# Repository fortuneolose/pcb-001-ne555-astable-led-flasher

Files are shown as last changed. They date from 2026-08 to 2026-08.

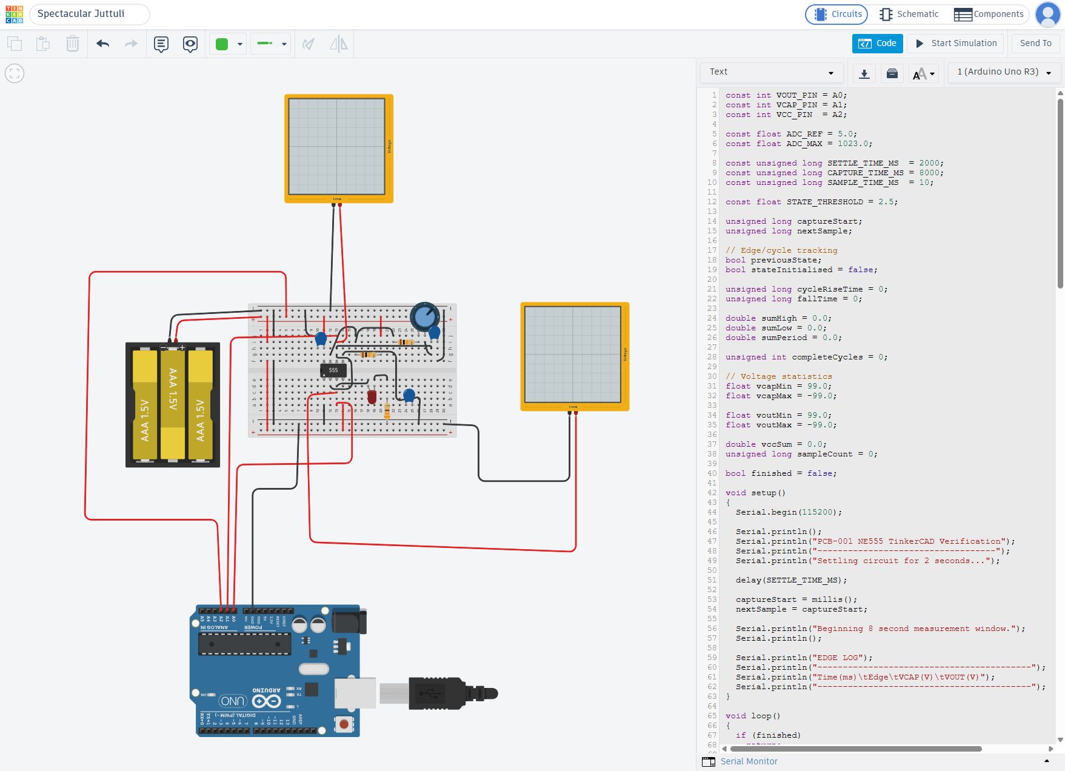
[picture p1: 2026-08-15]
simulation/tinkercad/evidence/arduino-code-panel.png

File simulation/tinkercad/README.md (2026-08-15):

# PCB-001 — Adjustable NE555 Astable LED Flasher

## Purpose

This directory preserves reproducible artifacts and evidence from the Tinkercad virtual breadboard verification stage.

The interactive Tinkercad circuit is cloud-hosted. This directory preserves code, measurements, circuit documentation, screenshots, and verification evidence derived from the live model. LTspice remains the precision electrical simulation model. Tinkercad represents the virtual breadboard and implementation translation. KiCad will become the authoritative PCB schematic and layout source.

The Tinkercad stage verifies practical pin mapping, component polarity, breadboard connectivity, potentiometer operation, instrumentation, and observable circuit behaviour. Static screenshots and the Arduino logger source were extracted directly from the live model during the 2026-08-14 inspection workflow.

## Current Verification Gates

- G1A Analytical Design: PASS
- G1B LTspice Full-Range Verification: PASS
- G1C LED Output Verification: PASS
- G1D Tinkercad Virtual Breadboard Verification: PASS

G1D is supported by minimum, midpoint, and maximum operating-point measurements.

## Live Project Metadata

- Project name: Spectacular Juttuli
- Tinkercad project URL: https://www.tinkercad.com/things/cFG6PsBppi5-spectacular-juttuli/editel
- Live inspection workflow date: 2026-08-14

## Preserved Static Evidence

- `evidence/breadboard-overview.png`
- `evidence/ne555-pin-wiring.png`
- `evidence/timing-network.png`
- `evidence/potentiometer-wiring.png`
- `evidence/led-output-stage.png`
- `evidence/arduino-logger-wiring.png`
- `evidence/arduino-code-panel.png`
- `evidence/tinkercad-schematic-view.png`

These files are genuine screenshots from the stopped live Tinkercad project. They do not establish powered waveforms or new measurement results.

## Corrected Dynamic Verification

On 2026-08-15, the Arduino logger was hardened against partial boundary cycles; the corrected source is preserved in commit `67e7f33`. The minimum, midpoint, and maximum operating points were re-run and all three passed. Genuine Serial Monitor and potentiometer evidence was captured at every operating point, with useful VOUT and VCAP scope evidence captured at midpoint and maximum. The electrical circuit itself was unchanged.

Corrected result records:

- `results/minimum_corrected_logger_2026-08-15.txt`
- `results/midpoint_corrected_logger_2026-08-15.txt`
- `results/maximum_corrected_logger_2026-08-15.txt`

Dynamic evidence:

- `evidence/potentiometer-minimum-2026-08-15.png`
- `evidence/serial-minimum-corrected-2026-08-15.png`
- `evidence/potentiometer-midpoint-2026-08-15.png`
- `evidence/serial-midpoint-corrected-2026-08-15.png`
- `evidence/scope-vout-midpoint-2026-08-15.png`
- `evidence/scope-vcap-midpoint-2026-08-15.png`
- `evidence/potentiometer-maximum-2026-08-15.png`
- `evidence/serial-maximum-corrected-2026-08-15.png`
- `evidence/scope-vout-maximum-2026-08-15.png`
- `evidence/scope-vcap-maximum-2026-08-15.png`

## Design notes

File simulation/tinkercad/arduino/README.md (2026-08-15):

# Arduino Instrumentation

The Arduino Uno R3 is instrumentation only; it does not implement the oscillator. The NE555 and its external timing network generate the oscillation.

## Intended Measurement Channels

- A0 -> NE555 VOUT / pin 3
- A1 -> VCAP timing-capacitor node
- A2 -> Tinkercad battery positive rail / VCC measurement
- GND -> circuit common ground

## Authoritative Source

The authoritative logger source was extracted verbatim from the live Tinkercad model during the 2026-08-14 inspection workflow. It is stored at:

`simulation/tinkercad/arduino/pcb001_ne555_logger.ino`

Do not reconstruct or replace this source from memory. Future changes must remain traceable to an explicitly reviewed live-model revision.

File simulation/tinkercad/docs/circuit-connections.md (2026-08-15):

# Circuit Connections

This document records design intent and the completed 2026-08-14 live-model inspection of the virtual breadboard.

## NE555 Connections

| Physical implementation item | Design intent | Live Tinkercad inspection status |
| --- | --- | --- |
| Pin 1 GND | GND | VERIFIED |
| Pin 2 TRIG | VCAP | VERIFIED |
| Pin 3 OUT | red LED -> 330 ohm -> GND | VERIFIED |
| Pin 4 RESET | positive supply | VERIFIED |
| Pin 5 CTRL | 10 nF capacitor -> GND | VERIFIED |
| Pin 6 THRS | VCAP | VERIFIED |
| Pin 7 DIS | RA/RB junction | VERIFIED |
| Pin 8 VCC | positive supply | VERIFIED |

## Timing Network and Supporting Components

Intended timing path:

```text
positive supply
-> RA = 10 kOhm
-> pin 7 DIS
-> fixed RB = 10 kOhm
-> 100 kOhm potentiometer used as rheostat
-> VCAP
-> C1 = 10 uF
-> GND
```

| Physical implementation item | Design intent | Live Tinkercad inspection status |
| --- | --- | --- |
| RA | 10 kOhm from positive supply to pin 7 DIS | VERIFIED |
| Fixed RB | 10 kOhm from pin 7 DIS toward the potentiometer | VERIFIED |
| Potentiometer | 100 kOhm, used as a rheostat between fixed RB and VCAP | VERIFIED |
| C1 timing capacitor | 10 uF from VCAP to GND | VERIFIED |
| CTRL capacitor | 10 nF from pin 5 CTRL to GND | VERIFIED |
| Decoupling capacitor | 100 nF VCC-to-GND supply decoupling | VERIFIED |
| LED output stage | red LED with 330 ohm resistor to GND | VERIFIED |
| Supply | 3 x AAA representation; nominal 4.5 V and approximately 4.49 V in recorded measurements | VERIFIED |
| Overall timing-network implementation | RA, fixed RB, rheostat, VCAP, and timing capacitor topology | VERIFIED |

## Potentiometer Wiring

- Value = 100 kOhm
- Terminal 1 -> fixed 10 kOhm RB
- Wiper -> VCAP
- Terminal 2 -> VCAP
- Wiper tied to outer terminal 2
- Used as a rheostat

## Reference-Designator Traceability

Design nomenclature:

- C1 = 10 uF timing capacitor
- C2 = 10 nF CTRL capacitor
- C3 = 100 nF decoupling capacitor

Live Tinkercad reference labels:

- CC1 = 10 uF timing capacitor
- C1 = 10 nF CTRL capacitor
- CC3 = 100 nF decoupling capacitor

This is a reference-designator naming difference only, not an electrical discrepancy. The exact powered rail voltage was not re-measured during this static inspection because the simulation remained stopped.

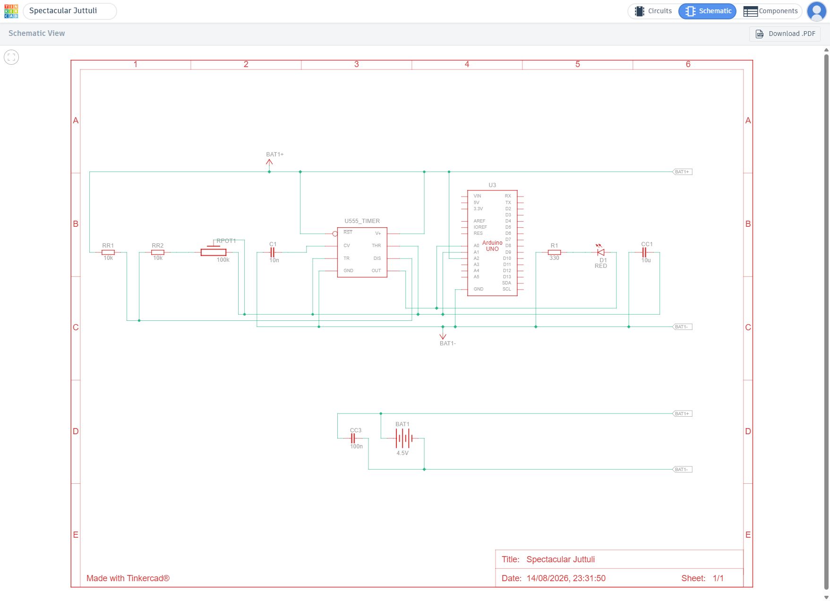
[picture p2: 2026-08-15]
simulation/tinkercad/evidence/tinkercad-schematic-view.png

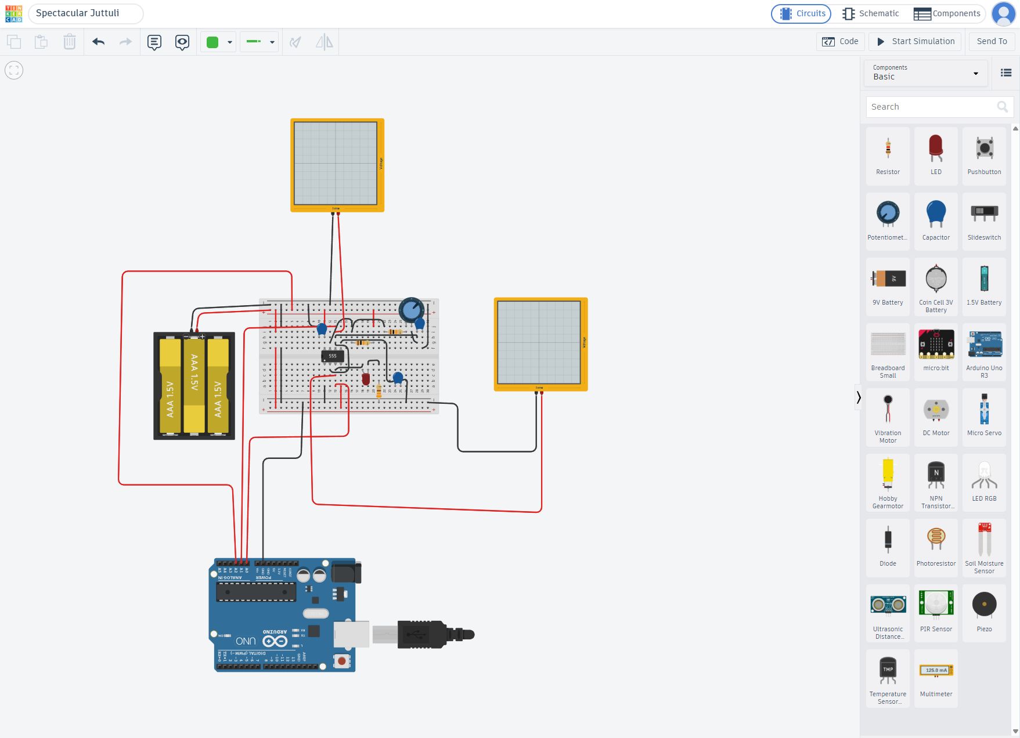
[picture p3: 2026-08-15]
simulation/tinkercad/evidence/breadboard-overview.png

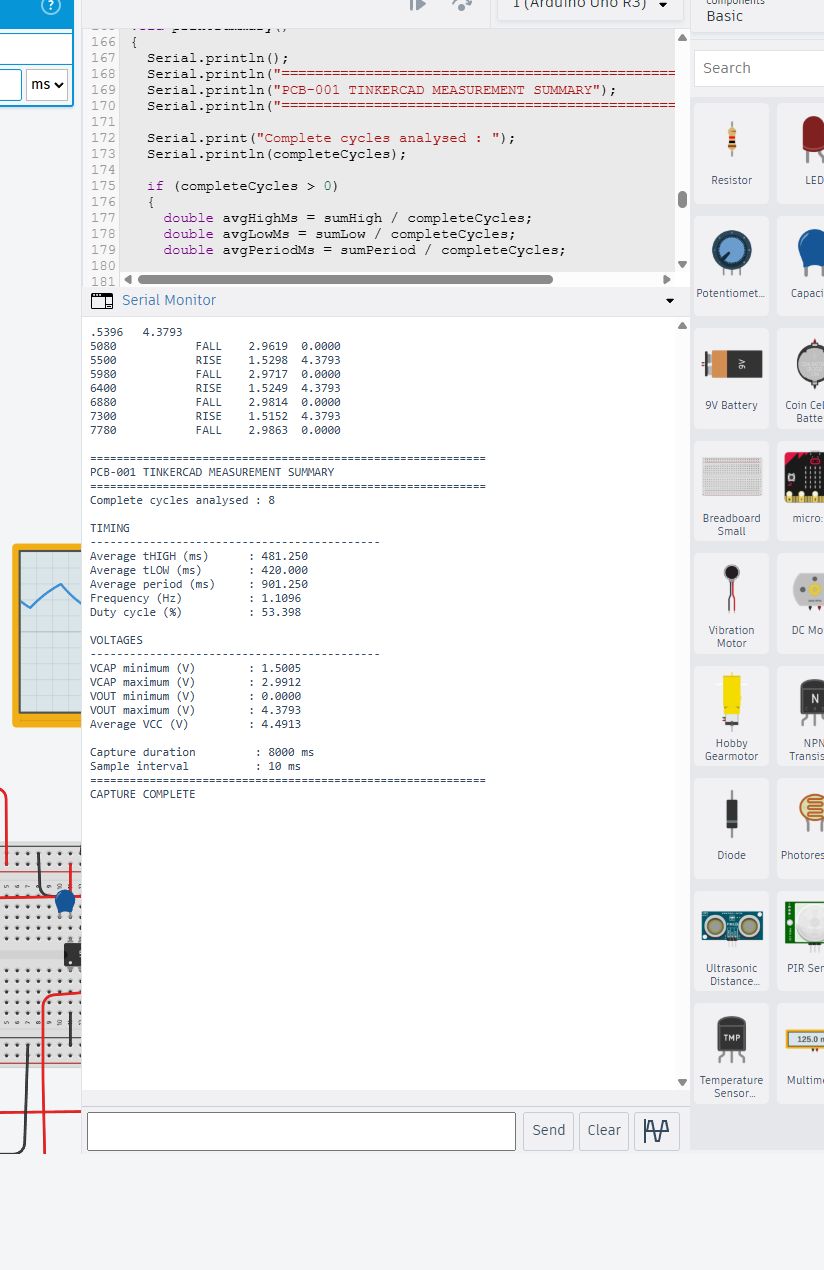
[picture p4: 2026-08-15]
simulation/tinkercad/evidence/serial-midpoint-corrected-2026-08-15.png

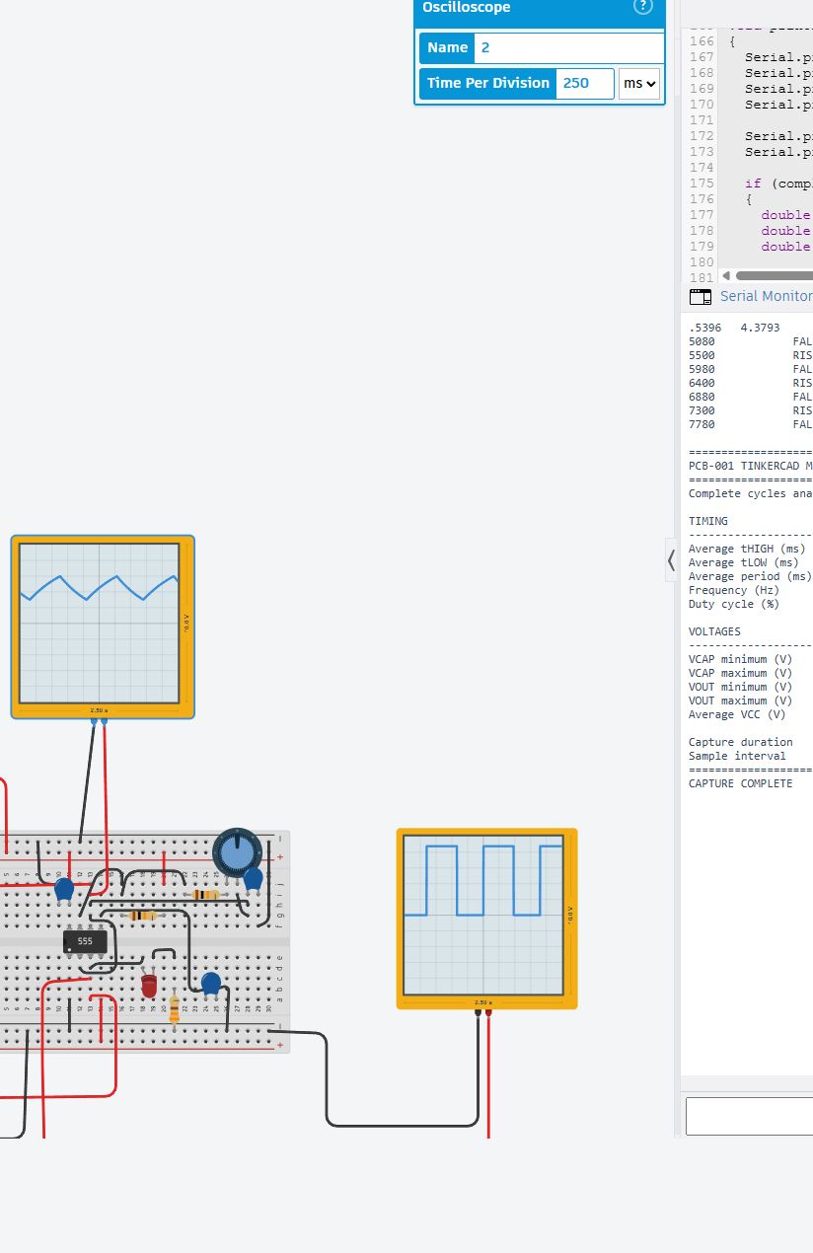
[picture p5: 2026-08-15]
simulation/tinkercad/evidence/scope-vcap-midpoint-2026-08-15.png

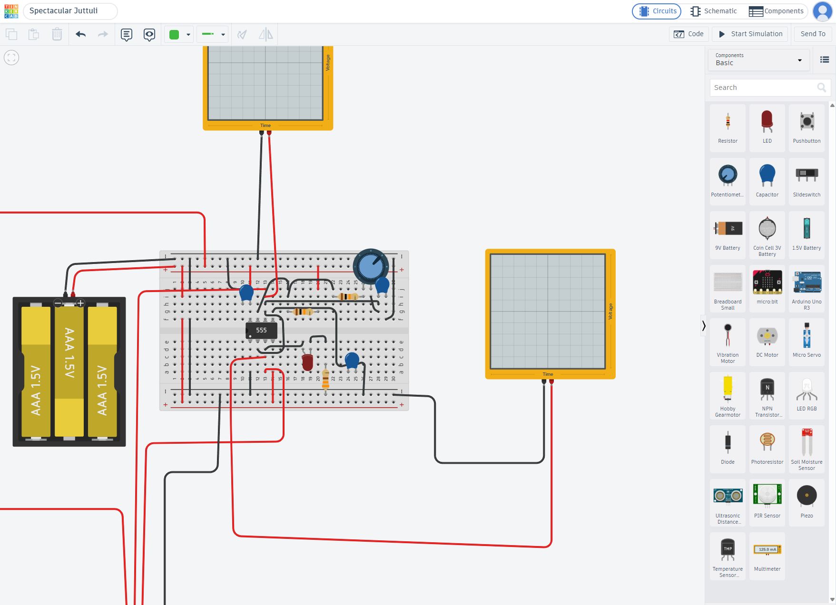
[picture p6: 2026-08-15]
simulation/tinkercad/evidence/timing-network.png

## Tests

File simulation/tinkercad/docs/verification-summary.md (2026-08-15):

# Tinkercad Three-Point Verification Summary

The virtual breadboard was instrumented using an Arduino Uno R3 ADC logger.

- Capture duration = 8000 ms
- Sample interval = 10 ms

VCAP repeatedly moved between approximately 1/3 VCC and 2/3 VCC, consistent with NE555 astable operation.

## Minimum Potentiometer Setting

- Complete cycles analysed = 38
- Average tHIGH = 138.421 ms
- Average tLOW = 69.500 ms
- Average period = 207.921 ms
- Frequency = 4.8095 Hz
- Duty cycle = 66.574 %
- VCAP minimum = 1.5005 V
- VCAP maximum = 2.9912 V
- VOUT minimum = 0.0000 V
- VOUT maximum = 4.3793 V
- Average VCC = 4.4901 V

## Midpoint Potentiometer Setting

- Complete cycles analysed = 8
- Average tHIGH = 481.250 ms
- Average tLOW = 420.000 ms
- Average period = 901.250 ms
- Frequency = 1.1096 Hz
- Duty cycle = 53.398 %
- VCAP minimum = 1.5005 V
- VCAP maximum = 2.9912 V
- VOUT minimum = 0.0000 V
- VOUT maximum = 4.3793 V
- Average VCC = 4.4913 V

## Maximum Potentiometer Setting

- Complete cycles analysed = 4
- Average tHIGH = 822.500 ms
- Average tLOW = 775.000 ms
- Average period = 1597.500 ms
- Frequency = 0.6260 Hz
- Duty cycle = 51.487 %
- VCAP minimum = 1.5005 V
- VCAP maximum = 2.9912 V
- VOUT minimum = 0.0000 V
- VOUT maximum = 4.3793 V
- Average VCC = 4.4916 V

Measured adjustable frequency range: approximately 0.6260 Hz to 4.8095 Hz

G1D: PASS

## Live Model Inspection

On 2026-08-14, the live Tinkercad implementation was inspected against `circuit-connections.md`.

- Electrical topology discrepancy: none observed
- Component-value discrepancy: none observed
- Potentiometer implementation: verified as a rheostat with the wiper tied to terminal 2
- Arduino instrumentation: verified
- Oscilloscope wiring: verified
- Exact powered rail voltage during this inspection: not verified because the simulation remained stopped
- Live waveforms during this inspection: not verified because the simulation remained stopped
- Tinkercad reference-designator naming differs from the design nomenclature, but electrical values and connections agree

## Corrected Logger Dynamic Re-Verification — 2026-08-15

The original logger could initialize `cycleRiseTime` when capture began while VOUT was already HIGH, allowing a partial initial HIGH interval to enter cycle timing. The corrected implementation uses explicit `haveRise` and `haveFall` state. Only a complete RISE -> FALL -> RISE sequence enters the averages, so incomplete first and final cycles are excluded. This was a logger robustness issue; it does not indicate a defect in the NE555 circuit.

### Minimum

- Complete cycles analysed = 37
- Average tHIGH = 138.351 ms
- Average tLOW = 69.486 ms
- Average period = 207.838 ms
- Frequency = 4.8114 Hz
- Duty cycle = 66.567 %
- VCAP minimum = 1.5005 V
- VCAP maximum = 2.9912 V
- VOUT minimum = 0.0000 V
- VOUT maximum = 4.3793 V
- Average VCC = 4.4900 V
- Capture duration = 8000 ms
- Sample interval = 10 ms

Comparison with the historical result:

- Historical cycles = 38
- Period difference = -0.083 ms
- Frequency difference = +0.0019 Hz
- Duty difference = -0.007 percentage points
- Result = PASS

### Midpoint

- Complete cycles analysed = 8
- Average tHIGH = 481.250 ms
- Average tLOW = 420.000 ms
- Average period = 901.250 ms
- Frequency = 1.1096 Hz
- Duty cycle = 53.398 %
- VCAP minimum = 1.5005 V
- VCAP maximum = 2.9912 V
- VOUT minimum = 0.0000 V
- VOUT maximum = 4.3793 V
- Average VCC = 4.4913 V
- Capture duration = 8000 ms
- Sample interval = 10 ms

All reported values match the historical midpoint result at printed precision. Result = PASS.

### Maximum

- Complete cycles analysed = 4
- Average tHIGH = 822.500 ms
- Average tLOW = 775.000 ms
- Average period = 1597.500 ms
- Frequency = 0.6260 Hz
- Duty cycle = 51.487 %
- VCAP minimum = 1.5005 V
- VCAP maximum = 2.9912 V
- VOUT minimum = 0.0000 V
- VOUT maximum = 4.3793 V
- Average VCC = 4.4916 V
- Capture duration = 8000 ms
- Sample interval = 10 ms

All reported values match the historical maximum result at printed precision. Result = PASS.

Corrected measured frequency range: 0.6260 Hz to 4.8114 Hz

All three corrected operating points: PASS

G1D Tinkercad Virtual Breadboard Verification: PASS — confirmed after corrected-logger dynamic re-verification.

The midpoint oscilloscopes used 250 ms/div, and the maximum oscilloscopes used 500 ms/div. Minimum scope screenshots were deliberately not preserved because the unchanged 100 us/div display was unsuitable for a period of approximately 208 ms. This omission is an evidence-quality decision, not a failed measurement.

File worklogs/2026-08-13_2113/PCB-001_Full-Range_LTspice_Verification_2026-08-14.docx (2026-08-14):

PCB-001

Full-Range LTspice Verification Worklog

NE555 Adjustable Astable LED Flasher

Work period: 14 August 2026, 08:29-10:12 (Ireland)

Stage | Pre-KiCad circuit verification
Primary objective | Verify the full timing-resistance range and close G1B
Sweep values | RB = 10 kOhm, 60 kOhm, 110 kOhm
Simulation tool | LTspice 24.1.10 for Windows
Final gate result | G1B - Full-Range LTspice Simulation Verification: PASS

This worklog records the parameter sweep, measurement-method failure, correction, final numerical results, engineering interpretation, and gate decision.

# 1. Session Objective and Starting State

Starting state: the midpoint design had already been verified at RB = 60 kOhm, with LTspice measurements closely matching the analytical NE555 astable equations. The remaining task was to verify the proposed adjustable range at the minimum, midpoint, and maximum effective timing resistance values.

- Minimum effective RB: 10 kOhm.
- Midpoint effective RB: 60 kOhm.
- Maximum effective RB: 110 kOhm.
- Goal: confirm timing, frequency, duty cycle, and capacitor switching thresholds at all three points before circuit freeze.

# 2. Parameter Sweep Implementation

R2 was parameterized using {RBval} and the following sweep was applied:

.step param RBval list 10k 60k 110k

The transient simulation remained: .tran 0 5s 0 1ms startup

# 3. Initial Measurement Failure and Root Cause

The first stepped run produced correct period, frequency, and capacitor-threshold values, but invalid negative tHIGH and duty-cycle values for steps 1 and 3. This did not indicate a circuit fault. It exposed a measurement-pairing fault in the original .meas expressions.

Step | RB | Initial tHIGH | Initial duty | Interpretation
1 | 10 kOhm | -0.069535 s | -33.37 % | Invalid - wrong edge pairing
2 | 60 kOhm | 0.485925 s | 53.82 % | Valid
3 | 110 kOhm | -0.764317 s | -47.85 % | Invalid - wrong edge pairing

Root cause: after TD = 1 s, the first FALL event can occur before the first RISE event. The original direct TRIG/TARG measurement therefore subtracted events in the wrong order for some sweep steps.

# 4. Corrected .meas Method

The measurement strategy was changed from direct edge-pairing to explicit edge timestamps. This made the measurement independent of the oscillator phase at the 1 s analysis cutoff.

Event timestamps

.meas tran TR1 WHEN V(vout)=2.5 TD=1s RISE=1
.meas tran TR2 WHEN V(vout)=2.5 TD=1s RISE=2
.meas tran TF1 WHEN V(vout)=2.5 TD=1s FALL=1
.meas tran TF2 WHEN V(vout)=2.5 TD=1s FALL=2

Derived measurements

.meas tran tHIGH PARAM if(TF1>TR1, TF1-TR1, TF2-TR1)
.meas tran PERIOD PARAM TR2-TR1
.meas tran tLOW PARAM PERIOD-tHIGH
.meas tran FREQ PARAM 1/PERIOD
.meas tran DUTY PARAM 100*tHIGH/PERIOD
.meas tran VCAP_MIN MIN V(vcap) FROM 1s TO 5s
.meas tran VCAP_MAX MAX V(vcap) FROM 1s TO 5s

Key improvement: tHIGH now selects the correct falling edge whether the first post-1 s event is a rise or a fall. tLOW is then obtained from PERIOD - tHIGH, removing unnecessary edge-pair ambiguity.

# 5. Final Full-Range Measurement Results

RB | tHIGH (s) | tLOW (s) | Period (s) | Freq (Hz) | Duty (%) | VCAP min (V) | VCAP max (V)
10 kOhm | 0.138819 | 0.069535 | 0.208354 | 4.799530 | 66.6265 | 1.665666 | 3.334334
60 kOhm | 0.485925 | 0.416961 | 0.902886 | 1.107560 | 53.8191 | 1.665667 | 3.334333
110 kOhm | 0.833112 | 0.764317 | 1.597429 | 0.626006 | 52.1533 | 1.665668 | 3.334332

# 6. Analytical vs LTspice Verification

RB | Quantity | Analytical | LTspice | Relative error
10 kOhm | tHIGH | 0.138600 s | 0.138819 s | +0.158%
| tLOW | 0.069300 s | 0.069535 s | +0.339%
| Frequency | 4.8100 Hz | 4.79953 Hz | -0.218%
| Duty | 66.667% | 66.6265% | -0.060%
60 kOhm | tHIGH | 0.485100 s | 0.485925 s | +0.170%
| tLOW | 0.415800 s | 0.416961 s | +0.279%
| Frequency | 1.1100 Hz | 1.10756 Hz | -0.220%
| Duty | 53.846% | 53.8191% | -0.050%
110 kOhm | tHIGH | 0.831600 s | 0.833112 s | +0.182%
| tLOW | 0.762300 s | 0.764317 s | +0.265%
| Frequency | 0.62739 Hz | 0.626006 Hz | -0.221%
| Duty | 52.174% | 52.1533% | -0.040%

Verification outcome: all timing and frequency quantities agree with the analytical model to substantially better than 1%. The largest observed relative deviation is approximately 0.34%, occurring in tLOW at RB = 10 kOhm.

# 7. Threshold and Behavioral Interpretation

- VCAP minimum remained approximately 1.666 V for all three sweep points.
- VCAP maximum remained approximately 3.334 V for all three sweep points.
- The timing resistance changes how quickly C1 moves between the thresholds; it does not materially change the thresholds themselves.
- The simulated LED flash-rate range is approximately 0.626 Hz to 4.800 Hz.
- Duty cycle moves from about 66.6% at the fastest setting toward 50% as RB becomes large relative to RA.

# 8. Gate Decision

Check | Result | Evidence
RB sweep executes at 10k / 60k / 110k | PASS | All three operating points converge and oscillate.
Frequency agreement | PASS | Approx. 0.22% error at all three points.
HIGH-time agreement | PASS | Maximum error approx. 0.18%.
LOW-time agreement | PASS | Maximum error approx. 0.34%.
Duty-cycle agreement | PASS | Maximum error approx. 0.06%.
VCAP thresholds | PASS | Approx. 1/3 VCC and 2/3 VCC across the sweep.

G1B - Full-Range LTspice Simulation Verification: PASS

Engineering conclusion: the proposed timing network is numerically verified over the intended adjustment range and is suitable to proceed toward final pre-KiCad output-stage verification.

# 9. Engineering Lessons from This Work Block

- A failed measurement does not automatically imply a failed design; verification logic must itself be validated.
- Stepped simulations can expose phase-dependent weaknesses that are invisible in a single operating-point test.
- Explicit event timestamps (TR1/TR2/TF1/TF2) are more robust than assuming a fixed edge order after a measurement delay.
- Analytical calculations remain valuable because they provide an independent target against which simulation can be judged.

# 10. Next Work Task

Immediate next task: LED-current verification. Measure the current through D1 / R3 at the operating points and confirm that the 330 Ohm resistor produces an acceptable LED current with the non-ideal NE555 output model.

- Measure LED current during VOUT HIGH.
- Check peak/steady current against the intended first-pass target.
- Confirm R3 = 330 Ohm remains appropriate.
- Once output-stage verification passes, freeze the circuit values and begin KiCad schematic capture.

PCB-001 | Full-Range LTspice Verification

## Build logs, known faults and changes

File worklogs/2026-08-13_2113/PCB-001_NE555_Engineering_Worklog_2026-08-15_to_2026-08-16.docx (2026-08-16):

ENGINEERING WORK SESSION RECORD

# PCB-001 NE555 Astable LED Flasher

KiCad schematic capture, simulation verification, PCB import and placement worklog

Control | Record
Project | PCB-001 - adjustable NE555 astable LED flasher
Session window | 15 August 2026 10:35 BST to 16 August 2026 01:12 BST
Active design phase | KiCad 10.0.4 / ngspice; Git repository on branch main
Record basis | Referenced task conversation plus repository and file inspection on 16 August 2026
End-of-session gate | Placement review PASS; routing, copper zone and DRC not started

Outcome The electrical design, ERC, footprint set and KiCad/ngspice midpoint verification passed. Fourteen physical footprints were imported and iteratively placed into coherent power, timing/core and output zones. The session stopped at placement freeze before any copper was routed.

# Executive status

Table 1 - Session gate summary

Gate | Scope | Status | Evidence / qualification
G1D | Prior Tinkercad verification | PASS | Corrected logger re-verified minimum, midpoint and maximum; commit 4ee50f8 was the clean entry baseline.
M1 | Native KiCad project scaffold | PASS | KiCad 10.0.4 project created and checkpointed at ed63b92.
M2 | Schematic and ERC | PASS | Functional capture completed; final ERC reported 0 errors and 0 warnings.
M2B | Physical footprint assignment | PASS | All 14 physical references have through-hole footprints; no blank assignments remained.
G1E | KiCad/ngspice schematic verification | PASS | Sustained oscillation confirmed at the 50 kOhm RV1-equivalent midpoint.
M3 | PCB import | PASS | Update PCB from Schematic reported 0 warnings and 0 errors and imported 14 physical footprints.
M3A | Component placement review | PASS | Placement frozen by visual review; latest reduced outline exists in autosave and is not yet baselined.
M3B | Routing and copper | OPEN | 0 segments, 0 vias and 0 zones in the latest inspected board artifact.
M4 | DRC / fabrication release | OPEN | No completed DRC, manufacturing package or procurement freeze.

Handoff condition The engineering design review reached placement freeze, but the repository is not in a clean handoff state. The tracked production and simulation files currently appear deleted while renamed project files and an autosave are untracked. Reconcile and checkpoint those files before routing.

# 1. Scope, evidence and time basis

This record reconstructs the complete KiCad-focused PCB-001 work session and its enabling repository checkpoints. It covers the clean entry state, project creation, manual schematic capture, ERC resolution, physical package decisions, KiCad/ngspice simulation, separation of production and simulation variants, PCB import, placement iterations and the final handoff state.

Timestamps are British Summer Time (UTC+01:00). The calendar span includes a long pause between the initial project-creation work and the evening capture/layout work; it is not a continuous labour-duration claim.

Table 2 - Evidence basis

Source | Used for | Reliability / limitation
Referenced task conversation | Primary chronology, decisions, screen-review results and declared gates. | High for actions recorded in text; attached placement images were not retained in the bounded reference.
Git history | Commit identifiers, timestamps, file scope and current branch/remote pointers. | Directly verified in repository.
Current KiCad files | Footprint count, routing count, outline geometry, production/simulation content and save-state divergence. | Directly inspected; current worktree is dirty.
Stored waveform | KiCad/ngspice transient result at midpoint equivalent. | Directly inspected and embedded as Figure 1.

# 2. Entry state and session objectives

The repository entered the KiCad phase on branch main with a clean worktree at commit 4ee50f8, test(tinkercad): verify corrected logger across full range. No KiCad project or custom KiCad libraries existed. The authoritative repository already separated docs, simulation and worklogs.

- Create native KiCad 10.0.4 project files without fabricating file contents or contaminating earlier verification evidence.
- Capture the verified nominal +5 V astable circuit manually, one functional block at a time.
- Resolve ERC transparently, then choose real through-hole packages and transfer the physical design to PCB Editor.
- Use KiCad/ngspice as an additional schematic-level check while keeping simulation-only helpers out of the manufactured PCB.
- Reach a mechanically usable placement freeze before routing.

# 3. Timestamped session chronology

Table 3 - Work-session timeline

Time (BST) | Stage | Recorded outcome
15 Aug 10:35 | Entry review | Clean main branch at 4ee50f8; no KiCad project present; directory and nomenclature plan approved.
15 Aug 11:37 | Project creation | KiCad 10.0.4 scaffold created with 16 symbol instances, no wiring, no footprints and empty PCB.
15 Aug 21:01 | Scaffold checkpoint | Saved native project, staged exactly three KiCad files and prepared controlled commit.
15 Aug 21:06 | Commit ed63b92 | Initial KiCad project scaffold committed.
15 Aug 21:13 | Commit 97b9be5 | Narrow KiCad transient ignore rules committed; design files remained trackable.
15 Aug 21:14-21:58 | Schematic capture | Power, timing, output and test-point networks wired; J1 convention and net labels finalized.
15 Aug 21:58 | ERC gate | First run showed two externally powered-net errors; +5 V and GND PWR_FLAG symbols resolved them; final 0/0 result.
15 Aug 22:00-22:42 | Footprints | All 14 physical references assigned through-hole footprints; post-assignment audit passed.
15 Aug 22:42 | PCB import | Update PCB from Schematic completed with 0 warnings/0 errors; 14-footprint ratsnest imported.
15 Aug 22:55-23:40 | KiCad/ngspice | Simulation readiness issues resolved sequentially; UA555 transient midpoint result passed.
15 Aug 23:51 | Variant separation | Decision made to keep production and simulation schematics separate.
15 Aug 23:55 | Commit e9d7818 | Production KiCad files, simulation variant, UA555 model and waveform evidence checkpointed.
16 Aug 00:03-01:10 | PCB placement | U1 rotated 180 degrees; functional groups tightened; provisional outline reduced; placement review passed.
16 Aug 01:12 | Session close | Routing deferred; next task defined as C3/U1 decoupling followed by VCAP/timing routing.

# 4. Repository checkpoints and configuration control

Table 4 - Repository checkpoints verified in Git

Commit | Time (BST) | Subject | Engineering significance
4ee50f8 | 15 Aug 10:29 | test(tinkercad): verify corrected logger across full range | Clean entry baseline for the KiCad work.
ed63b92 | 15 Aug 21:06 | chore(kicad): initialize PCB-001 project scaffold | Exactly the .kicad_pro, .kicad_sch and .kicad_pcb scaffold files.
97b9be5 | 15 Aug 21:13 | chore(repo): ignore KiCad transient files | Added rules for *-backups, .kicad_prl and ~*.lck while preserving design-file tracking.
e9d7818 | 15 Aug 23:55 | Update project files 2026-08-15 23:55:03 | Checkpointed production KiCad changes, UA555 model, waveform evidence and canonical simulation schematic.

## 4.1 Repository hygiene decision

KiCad backup ZIPs, .kicad_prl preferences and lock files were deliberately treated as transient. The .gitignore change was reviewed and committed separately from the design scaffold. The .kicad_pro, .kicad_sch and .kicad_pcb sources remained explicitly trackable. This created a clean configuration-control boundary before manual wiring.

## 4.2 Current repository state at handoff

Repository risk At inspection on 16 August, HEAD and origin/main both pointed to e9d7818, but the working tree was not clean. The four tracked production/simulation KiCad paths appeared deleted, while a placement-modified project, its autosave and a simulation schematic under 'New folder' were untracked. The remote alignment indicates that a push occurred after earlier per-checkpoint reports that said no push; that later push was not captured as a separate conversational action.

Tracked paths shown deleted:
kicad/pcb-001-ne555/pcb-001-ne555.kicad_pro
kicad/pcb-001-ne555/pcb-001-ne555.kicad_sch
kicad/pcb-001-ne555/pcb-001-ne555.kicad_pcb
simulation/kicad/pcb-001-ne555-sim/pcb-001-ne555.kicad_sch

Untracked working artifacts:
kicad/pcb-001-ne555/pcb-001-ne555-placement-modified.*
kicad/pcb-001-ne555/_autosave-pcb-001-ne555-placement-modified.kicad_pcb
simulation/kicad/New folder/pcb-001-ne555.kicad_sch

# 5. KiCad schematic capture

## 5.1 Native project scaffold

The project was created with KiCad 10.0.4 under kicad/pcb-001-ne555/ using basename pcb-001-ne555. The initial schematic contained 16 symbol instances: 14 physical references plus +5 V and GND power symbols. No wires, junctions, net labels, footprints, PWR_FLAG instances or PCB copper existed at the scaffold checkpoint.

## 5.2 Power, reset, control and decoupling block

- U1 pin 8 VCC and pin 4 RESET were connected to the global +5 V net.
- U1 pin 1 GND was connected to GND.
- U1 pin 5 CONT/CV was bypassed to GND by C2 = 10 nF.
- C3 = 100 nF was placed across +5 V and GND as the local supply decoupler.
- J1 polarity convention was deliberately settled as pad/pin 1 = +5 V and pad/pin 2 = GND.

## 5.3 Astable timing network

+5 V -> R1 10 kOhm -> U1 pin 7 DISCH junction
-> R2 10 kOhm -> RV1 100 kOhm rheostat -> VCAP
VCAP -> U1 pin 2 TRIG
VCAP -> U1 pin 6 THRES
VCAP -> C1 10 uF positive; C1 negative -> GND
VCAP -> TP4

RV1 was configured as a rheostat by tying the wiper to one outer terminal. Local VCAP labels replaced long schematic wires, improving auditability without changing connectivity. C1 polarity was reviewed explicitly: positive to VCAP, negative to GND.

## 5.4 Output and test interfaces

The output chain was captured as U1 pin 3 OUT / VOUT to D1, then R3 = 330 Ohm to GND. The final KiCad pad mapping shows D1 pad 2 (anode) on VOUT and pad 1 (cathode) feeding R3 toward GND. An early visual interpretation of LED orientation was rechecked against the actual symbol before the block was accepted.

- TP1 = +5 V
- TP2 = GND
- TP3 = VOUT
- TP4 = VCAP

## 5.5 Final pin-by-pin functional audit

Table 5 - NE555 functional pin audit

Pin | Function | Final net / path | Status
1 | GND | GND | PASS
2 | TRIG | VCAP | PASS
3 | OUT | VOUT -> D1 -> R3 -> GND | PASS
4 | RESET | +5 V | PASS
5 | CONT | C2 10 nF -> GND | PASS
6 | THRES | VCAP | PASS
7 | DISCH | R1/R2 junction | PASS
8 | VCC | +5 V | PASS

# 6. Electrical Rules Check

The first ERC run reported two errors and no warnings. Both errors were 'Input Power pin not driven by any Output Power pins'. This was expected because J1 is a passive connector supplying power from outside the PCB; neither +5 V nor GND contained a power-output pin.

- Added one PWR_FLAG to the +5 V net near J1.
- Added one PWR_FLAG to the GND net near J1.
- Did not suppress or ignore genuine connectivity checks.

Verification result Final ERC: 0 violations, 0 errors, 0 warnings. M2 / Schematic Complete: PASS.

# 7. Footprint assignment and physical package decisions

The board was intentionally standardized as a through-hole, hand-assembled and probe-friendly first build. All 14 physical references received footprints; the +5 V/GND symbols and PWR_FLAG instances did not transfer as physical parts.

Table 6 - Physical footprint register

Reference | Assigned footprint | Decision / check
C1 | Capacitor_THT:CP_Radial_D5.0mm_P2.00mm | 10 uF polarized radial electrolytic; pad 1 positive to VCAP.
C2, C3 | Capacitor_THT:C_Disc_D5.0mm_W2.5mm_P5.00mm | 10 nF control bypass and 100 nF decoupler; non-polarized.
D1 | LED_THT:LED_D5.0mm | 5 mm through-hole LED; edge visibility prioritized.
J1 | TerminalBlock_CUI:TerminalBlock_CUI_TB007-508-02_1x02_P5.08mm_Horizontal | Two-position 5.08 mm screw terminal; wire-entry direction must face edge.
R1-R3 | Resistor_THT:R_Axial_DIN0207_L6.3mm_D2.5mm_P10.16mm_Horizontal | Standard 0.25 W axial through-hole package.
RV1 | Potentiometer_THT:Potentiometer_Bourns_3386P_Vertical | 100 kOhm single-turn trimmer; screwdriver clearance required.
TP1-TP4 | TestPoint:TestPoint_THTPad_D2.0mm_Drill1.0mm | Plated through-hole probe pads; not assembled BOM items.
U1 | Package_DIP:DIP-8_W7.62mm | Through-hole 8-pin timer package; intended purchase discussed as NE555P-class PDIP.

Procurement caveat Footprint assignment is a geometry decision, not a final part-number freeze. Actual capacitor diameter/pitch, terminal-block orientation, trimmer pinout, LED lead polarity and NE555 package must be verified against selected manufacturer datasheets before fabrication.

# 8. PCB import

After saving the footprint assignments and rechecking the schematic, Update PCB from Schematic was run. The update dialog reported 0 warnings and 0 errors, with relinking, symbol-defined footprint replacement and field updates enabled. Destructive options such as deleting footprints with no symbols remained disabled.

- Fourteen physical footprints were imported as an initial overlapping cluster and dropped into clear working space.
- Cyan ratsnest lines were treated as connectivity feedback, not routed copper.
- The design explicitly checked that V1 and R4 simulation helpers were not proposed for the PCB.
- A provisional 50 mm x 50 mm Edge.Cuts rectangle was used as working space, not as a final size commitment.

# 9. KiCad/ngspice verification

## 9.1 Simulation-readiness issues resolved

Table 7 - Simulation setup issue log

Item | Observed condition | Resolution
Physical-only connector/test points | J1 and TP1-TP4 had no SPICE models. | Excluded from simulation.
Power source | +5 V symbols and PWR_FLAG do not generate voltage. | Added simulation-only V1 = 5 V DC source.
Passive value syntax | Human-readable values such as '10 kOhm' caused ngspice parsing errors. | Used SPICE notation: 10k, 330, 10u, 10n, 100n in the simulation variant.
LED model | The 'red LED' value did not resolve to a valid SPICE model. | Excluded D1 and R3 for the oscillator-only KiCad check; loading had already been verified elsewhere.
Potentiometer | Installed KiCad UI did not expose the expected potentiometer subtype path. | Excluded RV1 from SPICE and added R4 = 50k as the midpoint equivalent; R4 excluded from board/BOM/position files.
NE555 model | Timer:NE555D had no default subcircuit. | Attached self-contained uA555.sub, selected model UA555 and verified 1:1 pins 1-8.

## 9.2 Transient analysis setup

Analysis: TRAN (transient)
Time step: 1 ms
Final time: 10 s
Initial time: 0 s
Maximum time step: 1 ms
Use initial conditions: unchecked
Saved data: all voltages; currents/power/digital events not required
Plotted signals: V(VCAP), V(VOUT)
Compatibility: PSpice and LTspice

## 9.3 Verification result and interpretation

Table 8 - KiCad/ngspice midpoint result

Measure | Observed / configured value
Supply | 5 V
RA | 10 kOhm
Effective RB | R2 10 kOhm + R4 50 kOhm = 60 kOhm
Timing capacitance | 10 uF
VOUT | Approximately 0 to 4.8-4.9 V square wave
VCAP | Approximately 1.8 to 3.3 V cyclic charge/discharge
Period | Approximately 0.80 s
Frequency | Approximately 1.24-1.25 Hz
Duty cycle | Approximately 55%
Gate | G1E PASS - sustained astable oscillation confirmed

The ideal textbook estimate for RA = 10 kOhm, RB = 60 kOhm and C = 10 uF was about 0.901 s / 1.11 Hz, assuming exact one-third and two-thirds supply thresholds. The transistor-level UA555 model switched nearer 1.8 V and 3.3 V. Recalculating with those observed thresholds yields approximately 0.807 s / 1.24 Hz, closely matching the trace. The difference was therefore recorded as model behaviour, not a failed circuit.

Figure 1 - Stored KiCad/ngspice midpoint transient evidence (blue VOUT, red VCAP).

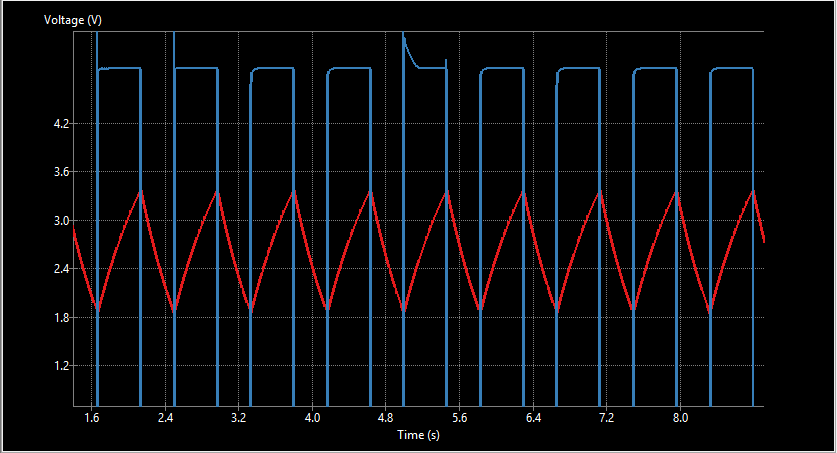
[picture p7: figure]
KiCad ngspice transient plot showing a blue square-wave VOUT trace near 0 to 4.9 volts and a red VCAP ramp between about 1.8 and 3.3 volts over several cycles.

Evidence file: kicad/evidence/midpoint-transient-2026-08-15.png

# 10. Production / simulation variant separation

After the successful transient run, the production design and KiCad simulation schematic were deliberately separated. The production schematic remains the manufacturing source; the simulation variant retains the analysis helpers and model assignments.

Table 9 - Variant responsibilities

Variant | Required contents | Configuration rule
Production schematic | J1 external 5 V input; physical RV1 100 kOhm; D1/R3 output; all four test points; 14 board footprints. | No V1; no R4; no simulation helpers in PCB/BOM.
Simulation schematic | V1 = 5 V; R4 = 50k midpoint substitute; UA555 model; physical-only exclusions as needed. | R4 excluded from board/BOM/position; V1 simulation-only; preserve waveform and model.

Portability risk The currently inspected simulation schematic stores an absolute Windows path to uA555.sub. Convert that assignment to a stable project-relative model path during repository cleanup, then rerun the transient check.

# 11. PCB placement iterations and layout decisions

Table 10 - Placement iteration log

Iteration | Change | Decision rationale
A - Import / provisional | 14-footprint cluster and 50 x 50 mm working outline. | Establish functional zones; do not route.
B - Functional zoning | J1/TP1/TP2 power area; R1/R2/RV1/C1/TP4 timing area; U1/C2/C3 core; R3/D1/TP3 output area. | Shorten local nets without chasing visual symmetry.
C - U1 orientation | U1 rotated 180 degrees. | Place pins 6/7 toward timing, pin 3 toward output, and supply pins where C3 can sit tightly.
D - Decoupling/control | C3 moved immediately below/next to U1 supply pads; C2 moved close to pin 5. | Electrical loop length took priority over aesthetic alignment.
E - Timing consolidation | R1/R2 pulled toward RV1/U1; C1 and TP4 tightened around VCAP. | Keep VCAP short and local; preserve RV1 screw access.
F - Mechanical edges | J1 retained at an accessible edge; D1 exposed at the edge; TP3 near output. | Verify terminal entry in 3D and preserve LED visibility/probe access.
G - Outline reduction | Placement compacted and Edge.Cuts pulled inward. | Stop shrinking before routing consumes clearance; leave roughly 2-3 mm ordinary edge clearance.
H - Placement freeze | Power across top, timing left, core center, output right; C3 below U1 and TP4 adjacent to timing node. | M3A PASS by review; no further broad shuffling before routing.

## 11.1 Final placement architecture

POWER / ENTRY TIMING + CORE OUTPUT
J1, TP1, TP2 R1, R2, RV1, C1, TP4 R3, D1, TP3
U1, C2, C3

Layout priorities:
C3 supply loop: extremely short
VCAP: short and separated from VOUT
J1: cable entry facing board edge
RV1: unobstructed screwdriver access
D1: visible at board edge
Test points: reachable with practical ground-lead geometry

## 11.2 Outline and save-state evidence

Table 11 - Board outline evidence

Artifact | Edge.Cuts rectangle | Timestamp | Interpretation
Named placement-modified board | 50.00 x 50.00 mm | Saved 16 Aug 01:00 | Older/provisional outline.
Newest autosave | 39.25 x 41.75 mm | Saved 16 Aug 01:10 | Latest reduced outline and likely final placement state.

Do not route yet Open and review the newest autosave, then deliberately save the approved placement into the authoritative named board file and checkpoint it. Routing against the older 50 x 50 mm saved file would lose the final outline decision.

# 12. Current board status

Table 12 - End-of-session board state

Item | Observed state | Status | Qualification
Physical footprints | 14 | PASS | All expected production references present.
Board outline | 39.25 x 41.75 mm in latest autosave | HOLD | Reduced outline is not yet in the named saved board.
Routed segments | 0 | OPEN | Routing intentionally not started.
Vias | 0 | OPEN | None required/placed yet.
Copper zones | 0 | OPEN | GND zone planned after explicit routing.
DRC | Not run to release criteria | OPEN | Expected because the board is unrouted.
Mounting holes | Decision pending | OPEN | Must be resolved before traces occupy remaining space.
Fabrication outputs | None | OPEN | No Gerbers, drill set, BOM or position files released.

# 13. Open risks and required controls

Table 13 - Risk register

ID | Level | Risk | Control / next action
R1 | High | Repository paths diverge from HEAD: authoritative tracked KiCad files appear deleted and renamed/untracked copies exist. | Reconcile paths, inspect diffs, stage intentionally and create a clean checkpoint before design edits.
R2 | High | Latest placement and 39.25 x 41.75 mm outline appear only in an autosave. | Open autosave, visually compare, save approved state under authoritative basename, then verify counts and outline.
R3 | High | Simulation variant is currently under an untracked 'New folder' path while the canonical tracked path appears deleted. | Move/Save As to simulation/kicad/pcb-001-ne555-sim/ and verify production/simulation separation.
R4 | Medium | UA555 assignment uses an absolute machine-specific model path. | Use a project-relative model reference and rerun ngspice after relocation.
R5 | Medium | No routing, ground zone or DRC has been completed. | Route in controlled priority order, add GND zone, then resolve every DRC finding.
R6 | Medium | Mechanical suitability is not frozen to exact purchased part numbers. | Check datasheets for C1/C2/C3 pitch/body, RV1 pinout, J1 orientation, LED polarity and DIP part.
R7 | Medium | Mounting-hole requirement is unresolved. | Decide before routing; if required, place holes and keepouts now.
R8 | Low | KiCad oscillator simulation excluded LED/R3 loading. | Treat G1E as oscillator verification; retain LTspice/Tinkercad evidence for loaded output behaviour.
R9 | Low | Attached placement screenshots are not preserved as repository evidence. | Capture and version a final 2D PCB Editor image and, optionally, a 3D view after placement save.

# 14. Next-session execution plan

Table 14 - Ordered next-session actions

Step | Action | Execution detail | Exit criterion
1 | Preserve the latest placement | Open the 01:10 autosave and the 01:00 named board side by side; confirm the intended placement and 39.25 x 41.75 mm outline. | Approved placement is safely saved under the authoritative project basename.
2 | Reconcile Git paths | Restore or intentionally rename the production project and canonical simulation variant; remove the accidental 'New folder' naming through normal save/move workflow. | git status shows only intended changes; no authoritative source is shown deleted unintentionally.
3 | Revalidate production schematic | Confirm no V1 or R4 in production; verify 14 physical footprints, J1 polarity, C1/LED polarity and all net labels; run ERC. | ERC = 0 errors, 0 warnings; PCB update proposes no simulation helpers.
4 | Revalidate simulation variant | Make uA555.sub path portable; confirm V1/R4 and all exclusions; rerun 1 ms / 10 s transient. | VOUT/VCAP oscillation reproduces the recorded midpoint result.
5 | Close mechanical decisions | Decide mounting holes; inspect F.Courtyard overlaps, J1 cable-entry direction, RV1 adjustment clearance and D1 visibility in 2D/3D. | Mechanical review recorded PASS before copper.
6 | Route C3 decoupling first | Use short/wide geometry between U1 supply pads and C3. Do not allow cosmetic placement to lengthen the loop. | C3/U1 loop is minimal and reviewable.
7 | Route VCAP/timing | Route pins 2/6, C1, RV1 and TP4, then the pin 7 / R1 / R2 timing path. Keep VOUT away from VCAP. | Timing nets are short, local and not parallel to the switching output for meaningful distance.
8 | Route output and power | Route VOUT -> R3 -> D1 / TP3, then +5 V distribution and remaining signals. | Power and output paths match the intended functional zoning.
9 | Add GND copper zone | Use an appropriate ground zone after deliberate routing; refill and inspect thermal reliefs and isolated islands. | Ground connectivity is complete and zone behaviour is visually reviewed.
10 | Run DRC and release checks | Resolve all unrouted/clearance/edge/silkscreen issues; inspect polarity and connector markings; generate fabrication data only after sign-off. | DRC clean; manufacturing review and exact part-number checks complete.

## 14.1 Routing design rules agreed in-session

Table 15 - Initial routing constraints

Net/class | Initial rule | Rationale
Ordinary signals | 0.25-0.30 mm | Use for low-current signals unless later DRC/fabrication constraints require adjustment.
+5 V | 0.50 mm | Wider than ordinary signals.
Explicit GND traces | 0.50 mm | Use where routed; a GND copper zone will be added later.
VCAP | Topology rule | Keep short; avoid meaningful parallel runs beside VOUT.
C3 decoupling | Priority rule | First route; shortest practical local supply loop.

# 15. Session close and sign-off statement

The session achieved the intended design-development objective: a cleanly audited NE555 astable schematic, ERC pass, complete through-hole footprint set, independent KiCad/ngspice midpoint verification, physical PCB import and a coherent placement architecture ready for routing. The electrical and placement decisions are sufficiently mature to continue, but the latest placement must first be recovered from autosave and the production/simulation file paths must be reconciled into a clean repository checkpoint.

Formal end state M3A Component Placement: PASS by engineering review. Configuration baseline: HOLD pending save/repository reconciliation. M3B Routing, GND zone, DRC and fabrication release: NOT STARTED.

# Appendix A - Evidence register

Table 16 - Evidence register

Type | Identifier / path | Purpose
Git | 4ee50f8 | Clean verified Tinkercad entry baseline.
Git | ed63b92 | Initial native KiCad scaffold.
Git | 97b9be5 | KiCad transient-file ignore policy.
Git | e9d7818 | Production schematic/PCB update, UA555 model, waveform and simulation schematic checkpoint.
Model | kicad/models/uA555.sub | Self-contained UA555 subcircuit; declaration .SUBCKT UA555 1 2 3 4 5 6 7 8.
Waveform | kicad/evidence/midpoint-transient-2026-08-15.png | Stored transient evidence embedded as Figure 1.
Production working files | kicad/pcb-001-ne555/pcb-001-ne555-placement-modified.* | Untracked renamed project at handoff; requires reconciliation.
Latest board autosave | kicad/pcb-001-ne555/_autosave-pcb-001-ne555-placement-modified.kicad_pcb | 14 footprints, 39.25 x 41.75 mm outline, 0 segments/vias/zones.
Current simulation working file | simulation/kicad/New folder/pcb-001-ne555.kicad_sch | Untracked simulation variant with V1/R4 and UA555 assignment.

# Appendix B - Status legend

Status | Meaning
PASS | Completed and supported by recorded evidence.
HOLD | Engineering content is acceptable, but configuration or save-state work is required before continuation.
OPEN | Required work has not yet been completed.

PCB-001 | Page

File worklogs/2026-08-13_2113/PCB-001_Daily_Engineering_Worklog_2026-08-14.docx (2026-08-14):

PCB-001

Adjustable NE555 Astable LED Flasher

Comprehensive Daily Engineering Worklog and Verification Record

14 August 2026

Project phase | Circuit verification before KiCad schematic capture
Coverage | LTspice full-range verification, LED output validation, Tinkercad breadboard modelling, oscilloscope checks, Arduino data logging
Primary tools | LTspice 24.1.10, Autodesk Tinkercad Circuits, Arduino Uno R3 logger
Reference supply | 5.0 V analytical/LTspice target; ~4.49 V measured Tinkercad battery supply
Document cutoff | 14 August 2026, 20:10 local time
Overall status | Pre-KiCad analytical, SPICE and virtual-breadboard verification complete

Purpose: preserve a traceable engineering record of calculations, modelling decisions, verification evidence, measurement methodology, faults found, corrections made, and the final pre-KiCad gate decision.

# Document Map

1. Executive Summary

2. Daily Worklog Chronology

3. Verified Electrical Design Baseline

4. Analytical Calculations and Expected Behaviour

5. LTspice Construction and Midpoint Verification

6. LTspice Full-Range Sweep and Measurement Correction

7. LED Output-Stage Verification

8. Tinkercad Virtual Breadboard - Purpose and Architecture

9. Tinkercad Construction Worklog

10. Oscilloscope Instrumentation

11. Arduino Uno R3 Measurement Logger

12. Tinkercad Quantitative Results: Minimum, Midpoint, Maximum

13. Three-Way Verification Comparison

14. Verification Gates and Design-Freeze Decision

15. Issues, Corrections, and Engineering Lessons

16. Next Work Package - KiCad Schematic Capture

Appendix A. Final Arduino Measurement Logger

Appendix B. Final LTspice .meas / .step Block

Appendix C. Pre-KiCad Quick Reference

# 1. Executive Summary

The work completed on 14 August 2026 closed the full pre-KiCad verification chain for PCB-001. The NE555 astable circuit was first checked analytically, then verified in LTspice at three timing-resistance operating points, then reconstructed as a virtual breadboard in Tinkercad, instrumented with virtual oscilloscopes, and finally measured quantitatively with an Arduino Uno R3 acting purely as a data logger.

- Midpoint LTspice measurements matched the analytical model to substantially better than 1% for timing and threshold quantities.
- A full LTspice parameter sweep verified effective RB values of 10 kOhm, 60 kOhm and 110 kOhm, corresponding to fast, midpoint and slow flash settings.
- An initial .meas edge-pairing method produced negative tHIGH values at two sweep points; the test method, not the circuit, was diagnosed and corrected using explicit rising/falling edge timestamps.
- The LED branch was initially simulated with a 1N4148 diode, revealing an unrealistically high 12.7 mA branch current. Replacing it with an LED model reduced the simulated peak current to approximately 9.0 mA, validating the 330 Ohm resistor choice.
- The verified circuit was reconstructed physically in Tinkercad using the real 555 pinout, breadboard rows, a 100 kOhm potentiometer, timing capacitor, bypass/decoupling capacitors and LED branch.
- Tinkercad used a 3 x 1.5 V battery pack, giving an Arduino-measured average supply near 4.49 V. The 555 timing thresholds therefore appeared near 1.50 V and 2.99 V, as expected from 1/3 VCC and 2/3 VCC.
- Arduino logging quantitatively verified all three potentiometer positions. Measured frequencies were 4.8095 Hz, 1.1096 Hz and 0.6260 Hz for minimum, midpoint and maximum resistance respectively.
- All analytical, LTspice and Tinkercad results are mutually consistent. The design is ready for KiCad schematic capture, with exact physical part/footprint selection still to be completed before PCB layout.

Overall daily gate result: ANALYTICAL DESIGN PASS -> LTSPICE FULL-RANGE PASS -> LED OUTPUT PASS -> TINKERCAD FULL-RANGE VIRTUAL BREADBOARD PASS -> READY FOR KICAD SCHEMATIC CAPTURE.

# 2. Daily Worklog Chronology

Stage | Work completed
Morning - LTspice midpoint check | Ran the verified midpoint circuit (RA=10 kOhm, RB=60 kOhm, C=10 uF), displayed VOUT and VCAP, then added .meas statements for timing and threshold values.
Morning - numerical LTspice confirmation | Measured tHIGH=0.485925 s, tLOW=0.416961 s, T=0.902886 s, f=1.10756 Hz, duty=53.819%, VCAP min=1.66567 V and max=3.33433 V.
Morning - full RB sweep | Parameterized RB and swept 10 kOhm, 60 kOhm and 110 kOhm. Frequency and capacitor thresholds were immediately correct across the range.
Morning - .meas debug | Negative tHIGH and duty values at steps 1 and 3 were traced to edge ordering after TD=1 s. Replaced direct edge pairing with explicit TR1/TR2/TF1/TF2 event timestamps and robust derived timing calculations.
Late morning - LED output verification | Measured output and LED branch current. Discovered D1 was a 1N4148 silicon diode rather than an LED. Replaced the model with an LED proxy and re-ran the current measurements.
Midday/afternoon - analytical consolidation | Reviewed the RC exponential law, origin of the 0.693 = ln(2) coefficient, thresholds, high/low times, period, frequency, duty cycle and LED resistor calculations before breadboard modelling.
Afternoon - Tinkercad construction | Built the circuit incrementally on a virtual breadboard: 555 power/reset, RA, fixed RB, 100 kOhm pot, VCAP node, C1, C2, C3, LED and 330 Ohm resistor.
Afternoon - Tinkercad instrumentation | Added oscilloscopes for VOUT and VCAP; corrected the timebase from nanoseconds to the 100-200 ms/div range appropriate to the oscillator.
Evening - Arduino logger | Added an Uno R3 as a passive measurement instrument on A0=VOUT, A1=VCAP, A2=VCC, with common GND. Diagnosed an initial reference-wiring error and corrected the logger.
Evening - three-point Tinkercad verification | Measured fast, midpoint and slow positions with an 8 s / 10 ms logger. All three points passed and matched the analytical model closely.

# 3. Verified Electrical Design Baseline

Element | Verified value / connection | Purpose
Supply target | 5.0 V DC | Nominal final PCB operating point
Tinkercad supply | 3 x 1.5 V cells; measured ~4.49 V | Virtual-breadboard test supply
U1 | NE555 timer, astable mode | Oscillator / LED switching
RA | 10 kOhm | Charge-path timing resistor from VCC to DIS
RB fixed | 10 kOhm | Minimum timing resistance / protects against zero resistance
Potentiometer | 100 kOhm, used as a rheostat | Variable timing resistance
Effective RB | 10 kOhm to 110 kOhm | Full flash-rate control range
C1 | 10 uF | Timing capacitor at VCAP
C2 | 10 nF | CONTROL pin bypass to GND
C3 | 100 nF | Local VCC decoupling to GND
RLED | 330 Ohm | LED current limiting
LED | Visible LED; exact PCB BOM part not yet frozen | Visual output indicator

Electrical connectivity carried into all models

NE555 pin mapping (top view, notch/dot orientation respected):
Pin 1 GND -> GND
Pin 2 TRIG -> VCAP
Pin 3 OUT -> LED -> 330 Ohm -> GND
Pin 4 RESET -> VCC
Pin 5 CTRL -> 10 nF -> GND
Pin 6 THRS -> VCAP
Pin 7 DIS -> RA/RB junction
Pin 8 VCC -> VCC

Timing network:
VCC -> RA 10k -> Pin 7 DIS -> RBfixed 10k -> 100k pot -> VCAP
VCAP -> Pin 2 TRIG
VCAP -> Pin 6 THRS
VCAP -> C1 10uF -> GND

# 4. Analytical Calculations and Expected Behaviour

The NE555 timing capacitor follows the standard first-order RC exponential relation. During charging, the capacitor approaches VCC through RA+RB; during discharge, it approaches 0 V through RB. Because the 555 switches at approximately 1/3 VCC and 2/3 VCC, solving the exponential transition gives ln(2) = 0.693.

Charging relation:
VC(t) = VS + [VC(0) - VS] exp(-t/RC)

Discharging relation:
VC(t) = VC(0) exp(-t/RC)

For the 555 thresholds, the exponential term becomes 1/2, therefore:
t = RC ln(2) = 0.693 RC

Astable timing equations

tHIGH = 0.693 (RA + RB) C
tLOW = 0.693 RB C
T = tHIGH + tLOW = 0.693 (RA + 2RB) C
f = 1 / T
Duty = 100 * tHIGH / T

Setting | Effective RB | tHIGH (ms) | tLOW (ms) | Period (ms) | Frequency (Hz) | Duty
Minimum / fast | 10 kOhm | 138.600 | 69.300 | 207.900 | 4.8100 | 66.667%
Midpoint | 60 kOhm | 485.100 | 415.800 | 900.900 | 1.1100 | 53.846%
Maximum / slow | 110 kOhm | 831.600 | 762.300 | 1593.900 | 0.6274 | 52.174%

Thresholds. At the nominal 5 V design point the expected thresholds are approximately 1.667 V and 3.333 V. In Tinkercad, the measured battery rail was ~4.49 V, so the expected thresholds shift to approximately 1.50 V and 2.99 V while the ideal RC timing remains nearly unchanged.

LED resistor. Using a first-pass visible-LED forward drop of about 2 V, the 330 Ohm resistor predicts approximately (5-2)/330 = 9.09 mA. The later LTspice LED-model result was approximately 9.01 mA peak, confirming the resistor value.

# 5. LTspice Construction and Midpoint Verification

The LTspice circuit was assembled incrementally so that each physical/electrical connection could be inspected before simulation. The model used the built-in NE555 subcircuit, a 5 V source, the timing network, control bypass, supply decoupling and LED output branch.

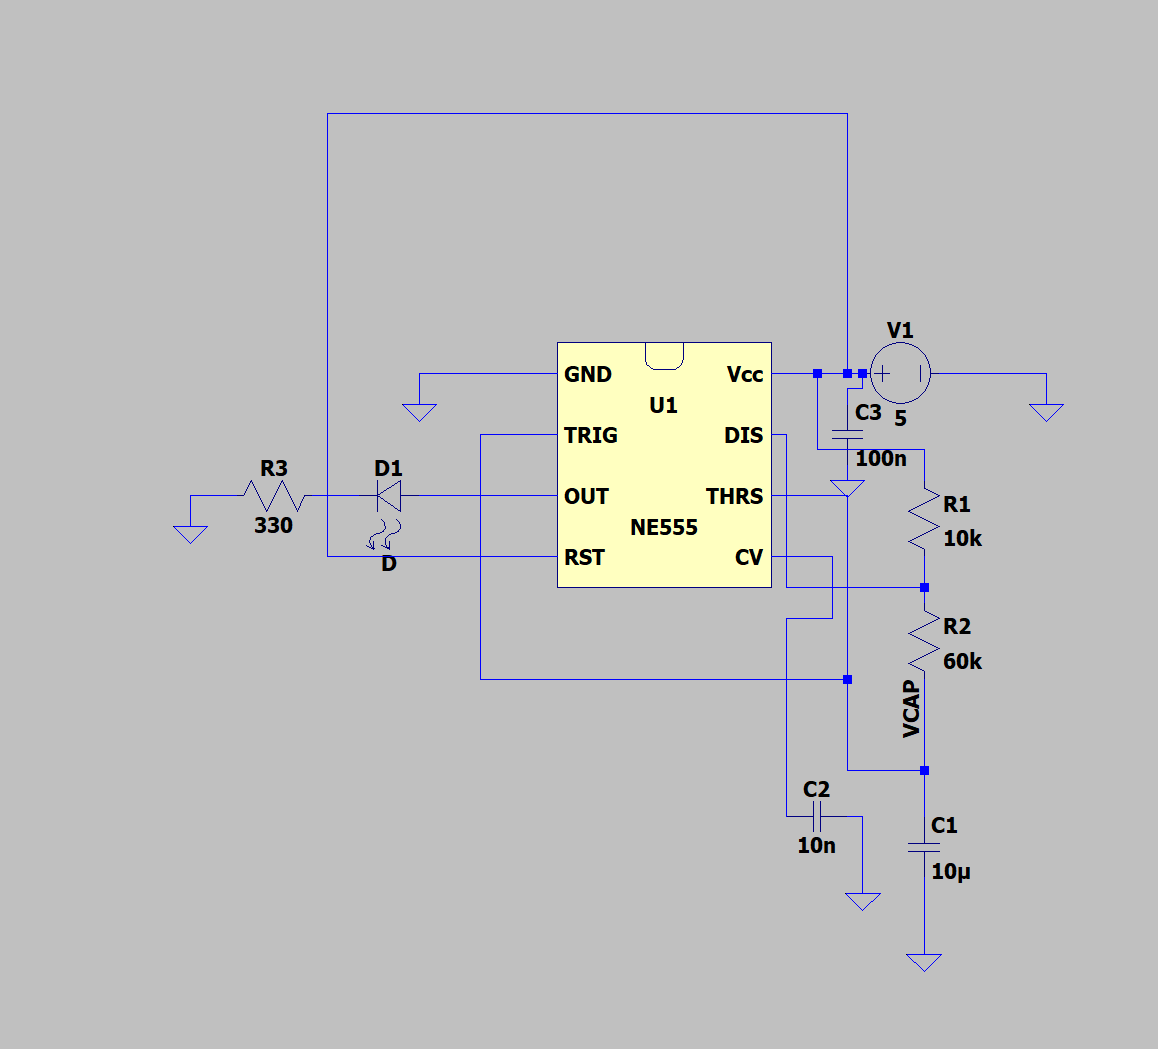
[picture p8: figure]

Figure 1. LTspice NE555 astable circuit after construction, including VCAP, output branch and decoupling.

- RESET was tied to VCC to keep the timer enabled.
- TRIGGER and THRESHOLD were tied to the timing-capacitor node VCAP.
- The 10 nF CONTROL capacitor and 100 nF VCC decoupling capacitor were separated from the 10 uF timing capacitor.
- The output node was labelled VOUT and the timing node VCAP for clean waveform and measurement references.
- Transient command used: .tran 0 5s 0 1ms startup.

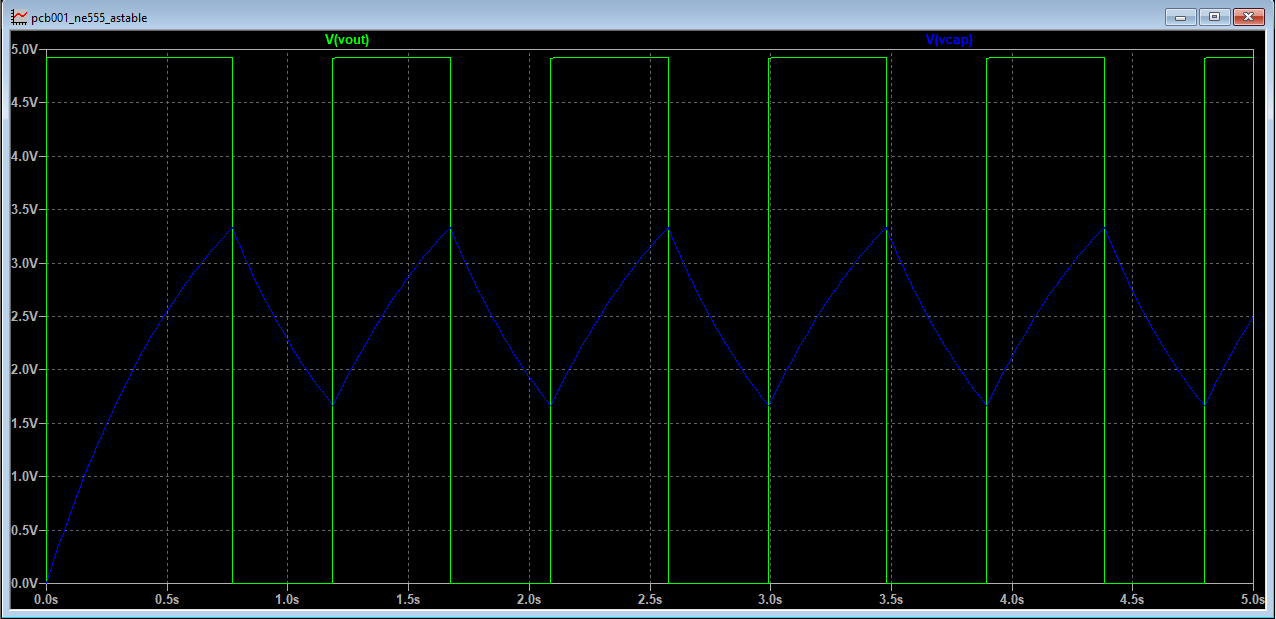
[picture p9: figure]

Figure 2. Successful LTspice transient result: VOUT square wave and VCAP exponential charge/discharge between approximately 1/3 and 2/3 VCC.

Quantity | Analytical | LTspice midpoint | Relative error
tHIGH | 485.100 ms | 485.925 ms | +0.170%
tLOW | 415.800 ms | 416.961 ms | +0.279%
Period | 900.900 ms | 902.886 ms | +0.220%
Frequency | 1.1100 Hz | 1.10756 Hz | -0.220%
Duty cycle | 53.846% | 53.819% | -0.050%
VCAP minimum | 1.6667 V | 1.66567 V | -0.060%
VCAP maximum | 3.3333 V | 3.33433 V | +0.030%

Midpoint LTspice verification result: PASS. The model reproduced the analytical timing and switching thresholds with sub-0.3% timing deviation.

# 6. LTspice Full-Range Sweep and Measurement Correction

The fixed midpoint timing resistor was parameterized so a single LTspice run could execute RB = 10 kOhm, 60 kOhm and 110 kOhm. The first sweep exposed a test-method problem: period and frequency were correct, but tHIGH and duty became negative at steps 1 and 3 because the first FALL after TD=1 s sometimes occurred before the first RISE.

Corrected edge-time measurement strategy

.step param RBval list 10k 60k 110k

.meas tran TR1 WHEN V(vout)=2.5 TD=1s RISE=1
.meas tran TR2 WHEN V(vout)=2.5 TD=1s RISE=2
.meas tran TF1 WHEN V(vout)=2.5 TD=1s FALL=1
.meas tran TF2 WHEN V(vout)=2.5 TD=1s FALL=2

.meas tran tHIGH PARAM if(TF1>TR1, TF1-TR1, TF2-TR1)
.meas tran PERIOD PARAM TR2-TR1
.meas tran tLOW PARAM PERIOD-tHIGH
.meas tran FREQ PARAM 1/PERIOD
.meas tran DUTY PARAM 100*tHIGH/PERIOD
.meas tran VCAP_MIN MIN V(vcap) FROM 1s TO 5s
.meas tran VCAP_MAX MAX V(vcap) FROM 1s TO 5s

RB | tHIGH (ms) | tLOW (ms) | Period (ms) | Frequency (Hz) | Duty | VCAP min / max
10 kOhm | 138.819 | 69.535 | 208.354 | 4.7995 | 66.627% | 1.6657 / 3.3343 V
60 kOhm | 485.925 | 416.961 | 902.886 | 1.1076 | 53.819% | 1.6657 / 3.3343 V
110 kOhm | 833.112 | 764.317 | 1597.429 | 0.6260 | 52.153% | 1.6657 / 3.3343 V

Engineering lesson: a failing measurement result is not automatically a failing circuit. The waveform and period data showed the oscillator was correct; the negative timing values were caused by a test-edge selection error. The measurement method was corrected rather than changing a working design.

# 7. LED Output-Stage Verification

The output branch was instrumented with .meas statements for branch current and VOUT extrema. The first run produced ILED,max ~= 12.735 mA. Inspection of D1 revealed that the selected device was a 1N4148 silicon switching diode, not an LED.

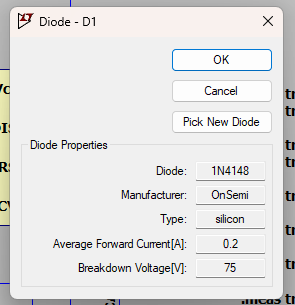
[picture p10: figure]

Figure 3. LTspice D1 properties showing the initially selected 1N4148 silicon diode model.

- With the 1N4148 model, the inferred forward drop was around the ordinary silicon-diode range, so the branch current was not representative of a visible LED.
- D1 was changed to a built-in LED model for simulation purposes. This model is a verification proxy; exact physical LED selection remains a BOM task.
- The 330 Ohm resistor was deliberately left unchanged so the original analytical design could be tested rather than tuned to the simulator.

RB | ILED max | ILED avg | VOUT max | VOUT min
10 kOhm | 9.005 mA | 3.980 mA | 4.9643 V | ~0 V
60 kOhm | 9.006 mA | 3.188 mA | 4.9643 V | ~0 V
110 kOhm | 9.006 mA | 2.950 mA | 4.9643 V | ~0 V

LED output-stage result: PASS. Peak current of approximately 9.0 mA agrees with the 9.1 mA first-pass hand calculation and confirms RLED = 330 Ohm for the current design.

# 8. Tinkercad Virtual Breadboard - Purpose and Architecture

Tinkercad was inserted as an explicit bridge between SPICE verification and KiCad PCB capture. LTspice verifies electrical behaviour using a device model; Tinkercad forces the design to be translated into actual DIP-8 pin numbers, breadboard connectivity, component orientation, potentiometer terminals and physical-style wiring.

Verification flow used today: hand analysis -> LTspice -> Tinkercad virtual breadboard -> Arduino quantitative logger -> KiCad next.

555 pin | Name | Tinkercad connection
1 | GND | Ground rail
2 | TRIGGER | VCAP
3 | OUTPUT | LED -> 330 Ohm -> GND
4 | RESET | Positive rail
5 | CONTROL | 10 nF -> GND
6 | THRESHOLD | VCAP
7 | DISCHARGE | RA/RB junction
8 | VCC | Positive rail

Supply difference. The virtual breadboard used a 3-cell 1.5 V holder, so the circuit ran at approximately 4.49 V rather than the 5.0 V LTspice design point. This was retained as a useful second operating condition. The 555 thresholds scaled with supply voltage, while the RC timing remained close to the analytical predictions.

# 9. Tinkercad Construction Worklog

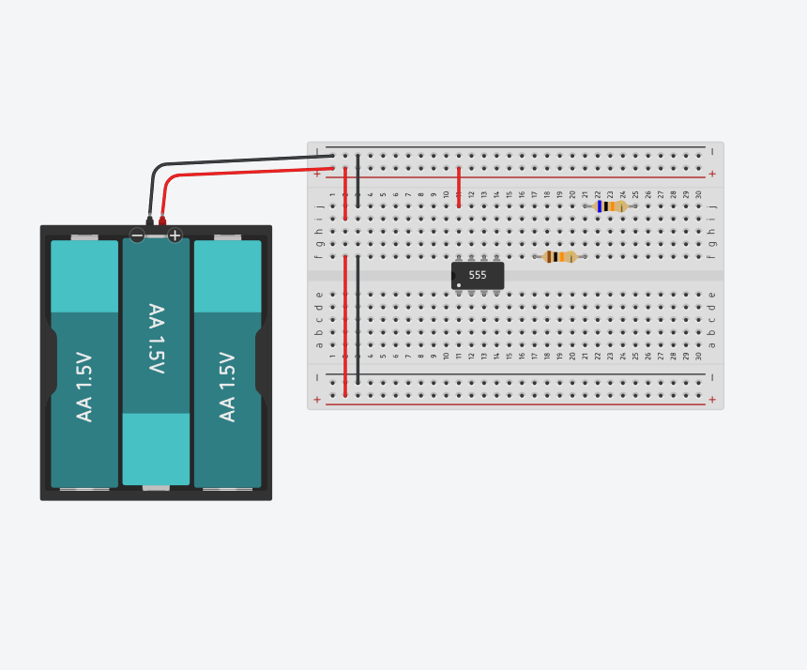
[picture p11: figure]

Figure 4. Early Tinkercad build: 555 straddling the breadboard centre gap, battery rails established and timing components staged.

1. Placed the 555 across the centre trench and mapped the physical DIP pin numbers from the orientation marker.

2. Established the positive and ground rails and connected the 555 power, ground and RESET connections.

3. Added the 100 nF supply decoupling capacitor and kept it separate from the timing network.

4. Connected RA = 10 kOhm from the positive rail to Pin 7 DISCHARGE.

5. Connected the fixed RB = 10 kOhm from Pin 7 toward the potentiometer.

6. Placed a 100 kOhm potentiometer and used it as a variable resistance element in the timing path.

7. Tied Pins 2 and 6 together to form VCAP and connected the pot output and C1 = 10 uF to that node.

8. Connected C2 = 10 nF from CONTROL (Pin 5) to ground.

9. Connected the LED branch from Pin 3 through the LED and 330 Ohm resistor to ground.

10. Performed repeated screenshot checks to verify breadboard columns and correct several visually ambiguous connections before simulation.

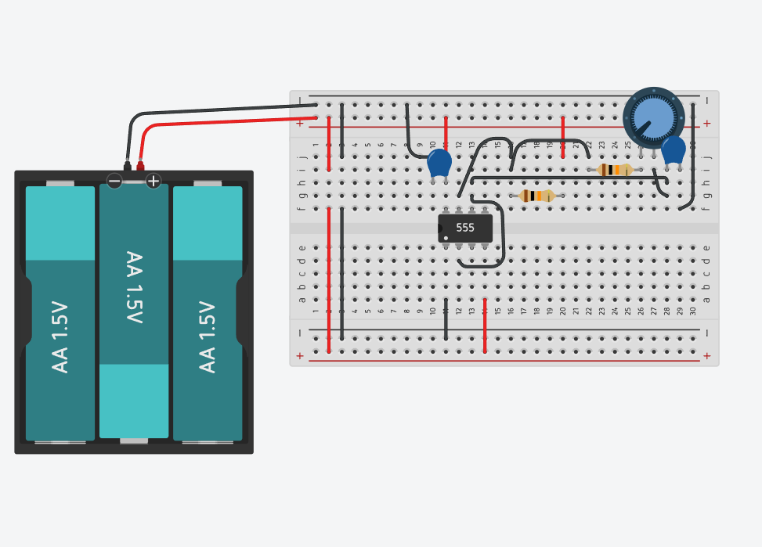
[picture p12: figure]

Figure 5. Tinkercad model after the timing network, potentiometer and VCAP interconnections were established.

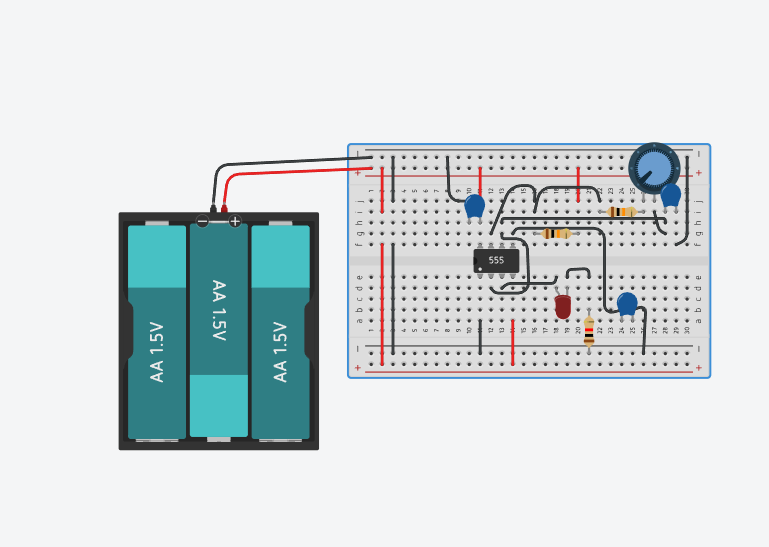
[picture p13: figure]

Figure 6. Completed virtual breadboard before Arduino data logging: NE555 astable, timing network, LED branch and auxiliary capacitors.

# 10. Oscilloscope Instrumentation

Two Tinkercad oscilloscopes were used to replicate the LTspice two-waveform observation. VOUT was probed at Pin 3 and VCAP at the Pins 2/6 timing node, each referenced to circuit ground.

- An initial scope timebase was accidentally set in nanoseconds. This showed only an isolated transition because the 555 period is hundreds of milliseconds to seconds.
- The timebase was corrected to the 100-200 ms/div range, allowing complete output cycles to be observed.
- At the 4.49 V breadboard supply, VCAP was expected to switch close to 1.50 V and 2.99 V, while VOUT switched between approximately 0 V and 4.38 V.

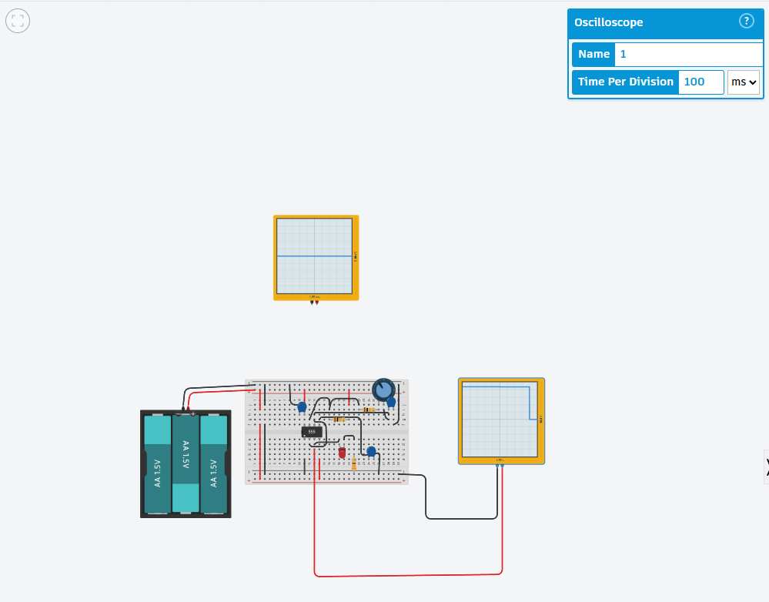
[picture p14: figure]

Figure 7. Tinkercad oscilloscope instrumentation used to observe the 555 output at a millisecond-scale timebase.

# 11. Arduino Uno R3 Measurement Logger

Because Tinkercad does not provide LTspice-style .meas automation, an Arduino Uno R3 was added solely as a passive data logger. It did not power or control the 555 circuit.

Arduino input | Circuit node | Purpose
A0 | Pin 3 / VOUT | Measure output HIGH/LOW waveform
A1 | VCAP / Pins 2+6 | Measure timing-capacitor voltage
A2 | Positive supply rail | Measure actual battery voltage
GND | Circuit ground rail | Common voltage reference

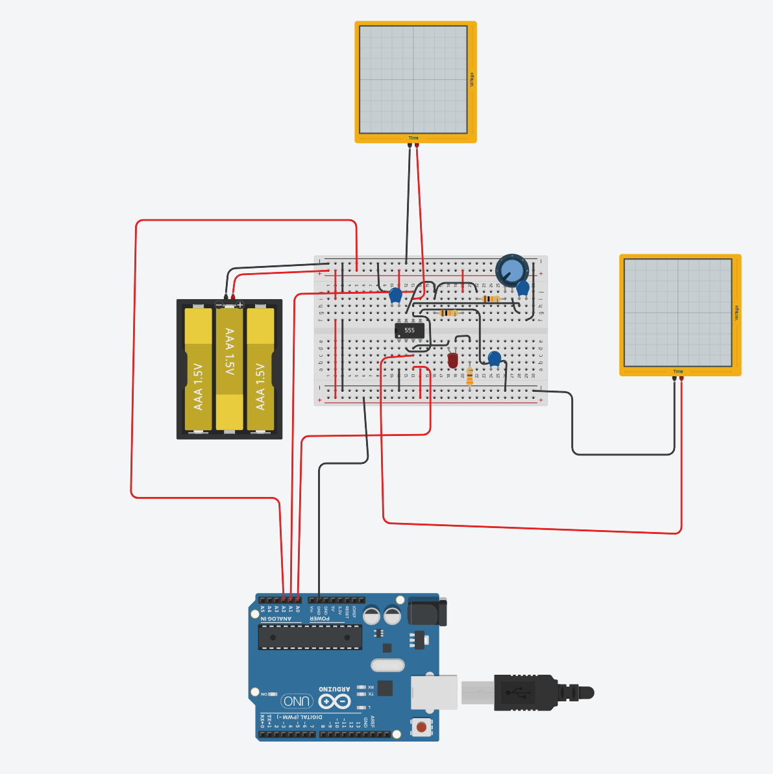
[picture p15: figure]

Figure 8. Arduino Uno R3 connected as a four-wire measurement instrument alongside the two Tinkercad oscilloscopes.

Reference-wiring fault and diagnosis. The first Arduino dataset contained negative voltages and VCC=0 V. This was traced to Arduino GND being referenced to the positive rail. After moving the logger ground to the actual negative rail, VOUT, VCAP and VCC became physically meaningful positive measurements. The timing pattern in the erroneous dataset was already consistent with the oscillator, which helped distinguish a reference problem from a circuit problem.

Logger development. The Arduino software evolved from raw CSV-style sampling into an engineering logger that waits for settling, samples every 10 ms, detects rising/falling output edges, rejects partial starting cycles, averages complete-cycle timing and prints a compact measurement summary.

Final measurement strategy

Measurement window: 8000 ms
Sample interval: 10 ms
State threshold: VOUT > 2.5 V => HIGH

Edge logic:
LOW -> HIGH = RISE, starts a valid cycle
HIGH -> LOW = FALL, ends tHIGH
next RISE = ends tLOW and period

A partial cycle already in progress when capture begins is ignored for cycle averages.

# 12. Tinkercad Quantitative Results: Minimum, Midpoint, Maximum

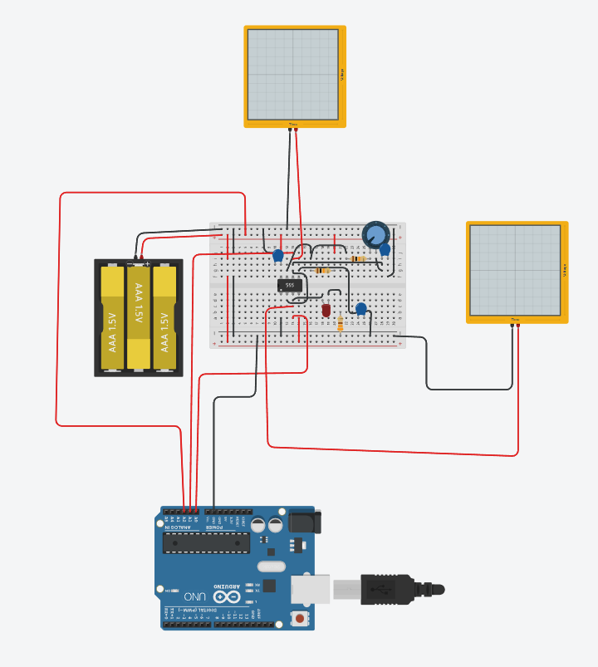
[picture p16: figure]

Figure 9. Tinkercad/Arduino configuration used for the minimum-resistance (fast) potentiometer measurement.

Metric | Minimum / fast result
Complete cycles analysed | 38
Average tHIGH | 138.421 ms
Average tLOW | 69.500 ms
Average period | 207.921 ms
Frequency | 4.8095 Hz
Duty cycle | 66.574%
VCAP min / max | 1.5005 V / 2.9912 V
VOUT min / max | 0.0000 V / 4.3793 V
Average VCC | 4.4901 V

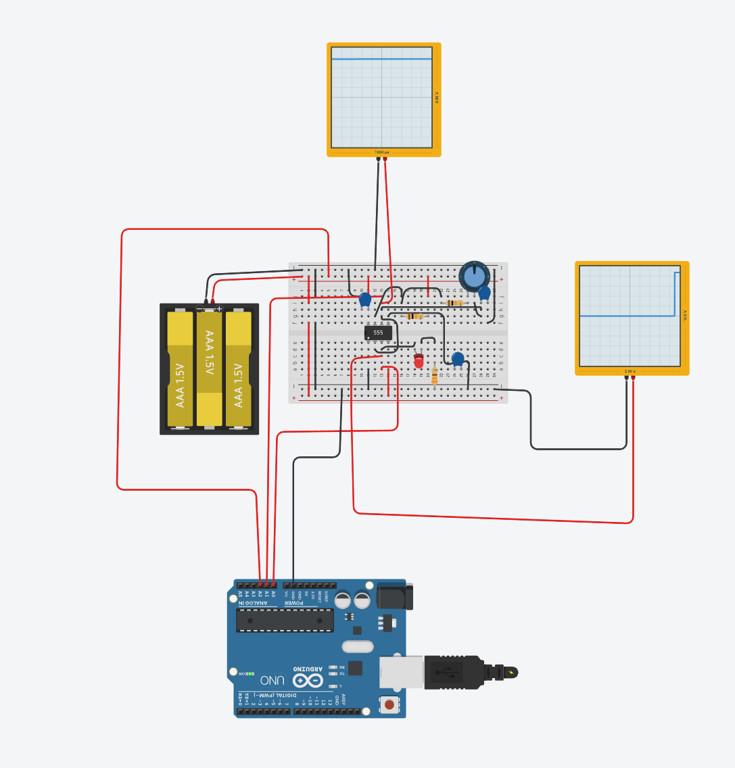
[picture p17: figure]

Figure 10. Tinkercad/Arduino configuration at the midpoint potentiometer setting.

Metric | Midpoint result
Complete cycles analysed | 8
Average tHIGH | 481.250 ms
Average tLOW | 420.000 ms
Average period | 901.250 ms
Frequency | 1.1096 Hz
Duty cycle | 53.398%
VCAP min / max | 1.5005 V / 2.9912 V
VOUT min / max | 0.0000 V / 4.3793 V
Average VCC | 4.4913 V

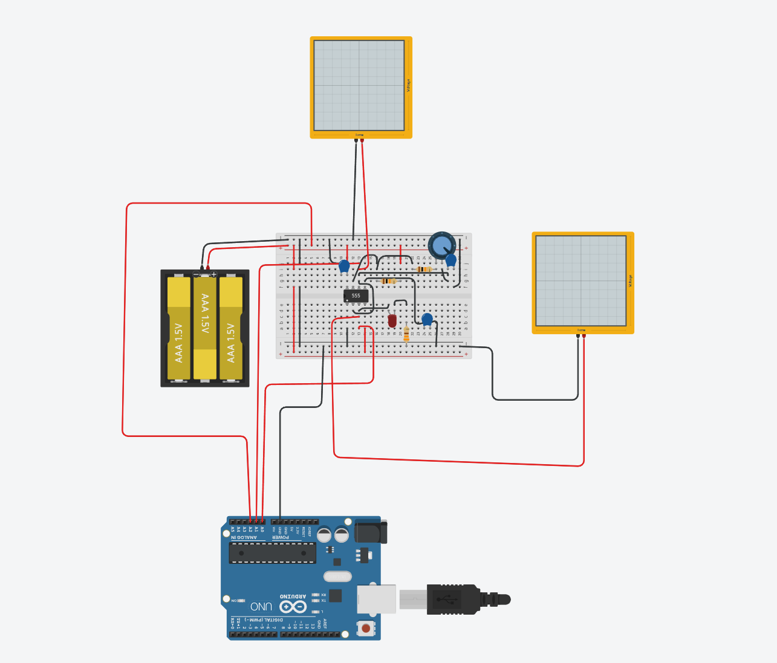
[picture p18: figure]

Figure 11. Tinkercad/Arduino configuration at the maximum-resistance (slow) potentiometer setting.

Metric | Maximum / slow result
Complete cycles analysed | 4
Average tHIGH | 822.500 ms
Average tLOW | 775.000 ms
Average period | 1597.500 ms
Frequency | 0.6260 Hz
Duty cycle | 51.487%
VCAP min / max | 1.5005 V / 2.9912 V
VOUT min / max | 0.0000 V / 4.3793 V
Average VCC | 4.4916 V

Threshold check. For VCC around 4.49 V, the ideal 1/3 and 2/3 thresholds are approximately 1.497 V and 2.994 V. All three Tinkercad runs measured approximately 1.5005 V and 2.9912 V, providing direct evidence that the timer is switching at the expected normalized thresholds.

# 13. Three-Way Verification Comparison

Setting | Quantity | Analytical | LTspice | Tinkercad
Minimum | tHIGH (ms) | 138.600 | 138.819 | 138.421
Minimum | tLOW (ms) | 69.300 | 69.535 | 69.500
Minimum | Period (ms) | 207.900 | 208.354 | 207.921
Minimum | Frequency (Hz) | 4.8100 | 4.7995 | 4.8095
Minimum | Duty (%) | 66.667 | 66.627 | 66.574
Midpoint | tHIGH (ms) | 485.100 | 485.925 | 481.250
Midpoint | tLOW (ms) | 415.800 | 416.961 | 420.000
Midpoint | Period (ms) | 900.900 | 902.886 | 901.250
Midpoint | Frequency (Hz) | 1.1100 | 1.1076 | 1.1096
Midpoint | Duty (%) | 53.846 | 53.819 | 53.398
Maximum | tHIGH (ms) | 831.600 | 833.112 | 822.500
Maximum | tLOW (ms) | 762.300 | 764.317 | 775.000
Maximum | Period (ms) | 1593.900 | 1597.429 | 1597.500
Maximum | Frequency (Hz) | 0.6274 | 0.6260 | 0.6260
Maximum | Duty (%) | 52.174 | 52.153 | 51.487

Setting | Tinkercad period error vs analytical | Tinkercad frequency error vs analytical | Interpretation
Minimum | +0.010% | -0.010% | Essentially exact period match
Midpoint | +0.039% | -0.036% | Essentially exact period match
Maximum | +0.226% | -0.222% | Excellent agreement at slow end

Sampling uncertainty. The Tinkercad logger sampled every 10 ms. Individual HIGH and LOW durations can therefore show several-millisecond quantization error at detected edges, especially at the midpoint and slow settings. Full periods are much less sensitive because edge quantization partially cancels and multiple complete cycles are averaged.

The most important cross-tool result is frequency: analytical 4.810 / 1.110 / 0.627 Hz, LTspice 4.800 / 1.108 / 0.626 Hz, and Tinkercad 4.810 / 1.110 / 0.626 Hz. The three independent representations agree across the full adjustment range.

# 14. Verification Gates and Design-Freeze Decision

Gate | Status | Evidence
G1A - Analytical design | PASS | RC exponential derivation, threshold calculations, three-point timing predictions, LED resistor calculation
G1B - Full-range LTspice | PASS | 10/60/110 kOhm sweep; timing and thresholds agree closely with analysis
G1C - LED output stage | PASS | LED model gives ~9.0 mA peak with 330 Ohm; VOUT remains well behaved
G1D - Tinkercad virtual breadboard | PASS | Physical-style wiring and three-point Arduino measurements reproduce expected operation
Pre-KiCad electrical design | READY | No unresolved functional issue remains before schematic capture

Item | Freeze status | Note
RA 10 kOhm | Frozen | Verified analytically and in both simulators
RB fixed 10 kOhm | Frozen | Provides defined minimum resistance
Potentiometer 100 kOhm | Frozen electrically | Exact physical part/footprint still to select
C1 10 uF | Frozen electrically | Exact dielectric/package still to select
C2 10 nF | Frozen | Control bypass
C3 100 nF | Frozen | Supply decoupling
RLED 330 Ohm | Frozen | ~9 mA peak in LTspice LED model
LED exact part number | Open BOM detail | Choose a real through-hole LED before footprint freeze
Nominal PCB supply | 5 V | Tinkercad 4.49 V run was a secondary verification condition

# 15. Issues, Corrections, and Engineering Lessons

Issue / observation | What happened | Engineering lesson
LTspice negative tHIGH values | Fixed edge numbers paired a FALL before a RISE for some stepped cases | Verify test logic before blaming the DUT; derive robust measurements from explicit event timestamps.
Wrong diode model | 1N4148 gave ~12.7 mA, inconsistent with the LED assumption | Model identity matters. A symbol that looks like a diode/LED is not enough; inspect the actual device model.
Tinkercad pin ambiguity | Several screenshots required close inspection of columns and DIP orientation | Physical translation is a separate verification problem from schematic correctness.
Scope timebase in ns | Only a transition was visible | Instrumentation must be configured to the expected signal timescale.
Arduino GND initially on wrong reference | Negative apparent voltages and VCC=0 V | A measurement system requires a correct shared reference; strange signs often indicate reference errors.
Partial-cycle averaging | A preliminary logger could count a cycle already in progress at capture start | Qualification logic should require a complete RISE-FALL-RISE sequence before accepting a cycle.
Tinkercad at 4.49 V vs LTspice at 5 V | Threshold voltages shifted but timing remained almost unchanged | Normalized 555 thresholds track VCC; RC timing is largely supply-independent in the ideal astable model.

# 16. Next Work Package - KiCad Schematic Capture

1. Create the KiCad project and schematic sheet for PCB-001.

2. Place NE555, RA, RB fixed, 100 kOhm potentiometer, C1/C2/C3, LED, 330 Ohm resistor, 5 V connector and test points.

3. Reproduce the verified connectivity exactly; do not introduce functional changes during capture.

4. Add net labels such as VCC, GND, VCAP and VOUT for clarity.

5. Select exact physical components and assign footprints only after checking real datasheets and package dimensions.

6. Run ERC and resolve/justify every warning before moving to PCB Editor.

7. Plan test points for +5 V, GND, VOUT and VCAP to preserve the same validation observability used in LTspice/Tinkercad.

8. Only after schematic/footprint review: board outline, placement, routing, GND pour, DRC and design review.

Do not redesign the circuit in KiCad. The next task is faithful capture of a circuit whose functionality has already been demonstrated three ways.

# Appendix A. Final Arduino Measurement Logger

The following code captures an 8-second window after a 2-second settle time, samples every 10 ms, records voltage extrema, detects edges and averages only complete RISE-FALL-RISE cycles. It is aligned with the 8-second evidence reported in this worklog.

const int VOUT_PIN = A0;
const int VCAP_PIN = A1;
const int VCC_PIN = A2;

const float ADC_REF = 5.0;
const float ADC_MAX = 1023.0;

const unsigned long SETTLE_TIME_MS = 2000;
const unsigned long CAPTURE_TIME_MS = 8000;
const unsigned long SAMPLE_TIME_MS = 10;
const float STATE_THRESHOLD = 2.5;

unsigned long captureStart;
unsigned long nextSample;

bool stateInitialised = false;
bool previousState = false;
bool haveRise = false;
bool haveFall = false;

unsigned long riseTime = 0;
unsigned long fallTime = 0;

double sumHigh = 0.0;
double sumLow = 0.0;
double sumPeriod = 0.0;
unsigned int completeCycles = 0;

float vcapMin = 99.0;
float vcapMax = -99.0;
float voutMin = 99.0;
float voutMax = -99.0;
double vccSum = 0.0;
unsigned long sampleCount = 0;
bool finished = false;

void setup() {
Serial.begin(115200);
Serial.println("PCB-001 NE555 TINKERCAD VERIFICATION");
Serial.println("Allowing circuit to settle for 2 seconds...");
delay(SETTLE_TIME_MS);

captureStart = millis();
nextSample = captureStart;

Serial.println("EDGE LOG");
Serial.println("Time(ms)\tEdge\tVCAP(V)\tVOUT(V)");
}

void loop() {
if (finished) return;

unsigned long now = millis();
unsigned long elapsed = now - captureStart;

if (elapsed >= CAPTURE_TIME_MS) {
printSummary();
finished = true;
return;
}

if (now >= nextSample) {
int rawVout = analogRead(VOUT_PIN);
int rawVcap = analogRead(VCAP_PIN);
int rawVcc = analogRead(VCC_PIN);

float vout = rawVout * ADC_REF / ADC_MAX;
float vcap = rawVcap * ADC_REF / ADC_MAX;
float vcc = rawVcc * ADC_REF / ADC_MAX;
bool currentState = (vout > STATE_THRESHOLD);

if (vcap < vcapMin) vcapMin = vcap;
if (vcap > vcapMax) vcapMax = vcap;
if (vout < voutMin) voutMin = vout;
if (vout > voutMax) voutMax = vout;
vccSum += vcc;
sampleCount++;

if (!stateInitialised) {
previousState = currentState;
stateInitialised = true;
}
else if (currentState != previousState) {
if (currentState) {
Serial.print(elapsed);
Serial.print("\tRISE\t");
Serial.print(vcap, 4);
Serial.print("\t");
Serial.println(vout, 4);

if (haveRise && haveFall) {
unsigned long tHigh = fallTime - riseTime;
unsigned long tLow = elapsed - fallTime;
unsigned long period = elapsed - riseTime;
sumHigh += tHigh;
sumLow += tLow;
sumPeriod += period;
completeCycles++;
}

riseTime = elapsed;
haveRise = true;
haveFall = false;
}
else {
Serial.print(elapsed);
Serial.print("\tFALL\t");
Serial.print(vcap, 4);
Serial.print("\t");
Serial.println(vout, 4);

if (haveRise) {
fallTime = elapsed;
haveFall = true;
}
}
previousState = currentState;
}

nextSample += SAMPLE_TIME_MS;
}
}

void printSummary() {
Serial.println("============================================================");
Serial.println("PCB-001 TINKERCAD MEASUREMENT SUMMARY");
Serial.println("============================================================");
Serial.print("Complete cycles analysed : ");
Serial.println(completeCycles);

if (completeCycles > 0) {
double avgHighMs = sumHigh / completeCycles;
double avgLowMs = sumLow / completeCycles;
double avgPeriodMs = sumPeriod / completeCycles;
double frequencyHz = 1000.0 / avgPeriodMs;
double dutyPercent = 100.0 * avgHighMs / avgPeriodMs;

Serial.println("TIMING");
Serial.print("Average tHIGH (ms) : "); Serial.println(avgHighMs, 3);
Serial.print("Average tLOW (ms) : "); Serial.println(avgLowMs, 3);
Serial.print("Average period (ms) : "); Serial.println(avgPeriodMs, 3);
Serial.print("Frequency (Hz) : "); Serial.println(frequencyHz, 4);
Serial.print("Duty cycle (%) : "); Serial.println(dutyPercent, 3);
}

Serial.println("VOLTAGES");
Serial.print("VCAP minimum (V) : "); Serial.println(vcapMin, 4);
Serial.print("VCAP maximum (V) : "); Serial.println(vcapMax, 4);
Serial.print("VOUT minimum (V) : "); Serial.println(voutMin, 4);
Serial.print("VOUT maximum (V) : "); Serial.println(voutMax, 4);
if (sampleCount > 0) {
Serial.print("Average VCC (V) : ");
Serial.println(vccSum / sampleCount, 4);
}

Serial.println("Capture duration : 8000 ms");
Serial.println("Sample interval : 10 ms");
Serial.println("============================================================");
Serial.println("CAPTURE COMPLETE");
}

# Appendix B. Final LTspice .meas / .step Block

.meas tran TR1 WHEN V(vout)=2.5 TD=1s RISE=1
.meas tran TR2 WHEN V(vout)=2.5 TD=1s RISE=2
.meas tran TF1 WHEN V(vout)=2.5 TD=1s FALL=1
.meas tran TF2 WHEN V(vout)=2.5 TD=1s FALL=2

.meas tran tHIGH PARAM if(TF1>TR1, TF1-TR1, TF2-TR1)
.meas tran PERIOD PARAM TR2-TR1
.meas tran tLOW PARAM PERIOD-tHIGH
.meas tran FREQ PARAM 1/PERIOD
.meas tran DUTY PARAM 100*tHIGH/PERIOD

.meas tran VCAP_MIN MIN V(vcap) FROM 1s TO 5s
.meas tran VCAP_MAX MAX V(vcap) FROM 1s TO 5s
.meas tran ILED_MAX MAX abs(I(R3)) FROM 1s TO 5s
.meas tran ILED_AVG AVG abs(I(R3)) FROM 1s TO 5s
.meas tran VOUT_MAX MAX V(vout) FROM 1s TO 5s
.meas tran VOUT_MIN MIN V(vout) FROM 1s TO 5s

.step param RBval list 10k 60k 110k
.tran 0 5s 0 1ms startup

# Appendix C. Pre-KiCad Quick Reference

Parameter | Value / expected range
Nominal PCB VCC | 5.0 V
RA | 10 kOhm
RB fixed | 10 kOhm
Potentiometer | 100 kOhm
Effective RB | 10-110 kOhm
C1 timing | 10 uF
C2 CONTROL bypass | 10 nF
C3 VCC decoupling | 100 nF
RLED | 330 Ohm
Expected LED peak current | ~9 mA
Fast frequency | ~4.81 Hz
Midpoint frequency | ~1.11 Hz
Slow frequency | ~0.627 Hz
Nominal 5 V thresholds | ~1.667 V and ~3.333 V
Tinkercad ~4.49 V thresholds | ~1.50 V and ~2.99 V

Reference material: project-supplied Philips Semiconductors NE/SA/SE555 family datasheet; LTspice 24.1.10 simulation logs; Tinkercad virtual-breadboard screenshots; Arduino Uno R3 Serial Monitor summaries captured during the 14 August 2026 work session.

PCB-001 | Adjustable NE555 LED Flasher | Daily Engineering Worklog

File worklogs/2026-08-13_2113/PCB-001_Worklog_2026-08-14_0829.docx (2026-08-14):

PCB-001

NE555 Astable LED Flasher

Detailed Engineering Worklog

Work period: 13 August 2026, 21:13 to 14 August 2026, 08:29 (Ireland)

Project | PCB-001 - Adjustable NE555 astable LED flasher
Repository | pcb-001-ne555-astable-led-flasher
Primary tools | LTspice 24.1.10, Git/GitHub, MATLAB, NE555 datasheet
Design stage | Circuit engineering and pre-KiCad simulation verification
Current verification point | Midpoint timing configuration verified
Document cutoff | 14 August 2026, 08:29

Purpose: preserve a traceable record of planning, design decisions, LTspice construction, numerical verification, issues encountered, and next actions.

# 1. Executive Summary

This work period advanced PCB-001 from project-organization refinement into a quantitatively verified LTspice implementation of the NE555 astable core. The central technical achievement was the successful numerical confirmation of the midpoint timing configuration (RA = 10 kOhm, RB = 60 kOhm, C = 10 uF) against the analytical model.

- Refined the repository/worklog organization and established timestamped session-record conventions.
- Revisited the project schedule and converted the 14 August circuit-engineering block from broad datasheet study into an execution-focused design session.
- Inserted LTspice simulation as a formal verification stage before KiCad schematic capture.
- Completed the analytical baseline for the NE555 astable timing network and LED output branch.
- Constructed the NE555 astable circuit incrementally in LTspice, correcting wiring ambiguities as they appeared.
- Added timing-node and output net labels to make waveform analysis deterministic and readable.
- Ran a 5 s startup transient simulation and visually verified VCAP and VOUT behavior.
- Added .meas statements and obtained numerical values for HIGH time, LOW time, period, frequency, duty cycle, and capacitor threshold extrema.
- Confirmed that the midpoint simulation matches the ideal analytical prediction to within approximately 0.3% for the main timing quantities.

## Current gate status

Gate | Status | Evidence
G0 - Project definition | PASS | Scope, repo, worklog structure, and milestones established.
G1A - Analytical design | PASS | Timing equations, threshold values, and LED resistor baseline completed.
G1B - Midpoint simulation | PASS | LTspice waveform and .meas results agree with analytical model.

# 2. Session Scope and Starting Point

Starting point. The previous worklog session had already established the project concept, high-level requirements, initial repository structure, NE555 datasheet orientation, MATLAB astable-cycle animation, and the need for a dedicated worklog folder. The new work period began with repository/worklog housekeeping and then moved into circuit-design verification.

Session end boundary used for this log. The prior worklog folder convention referenced 2026-08-13_2113. This document therefore logs work from that point through 08:29 on 14 August 2026.

# 3. Repository and Worklog Organization

- Recognized that the original project-directory creation command did not include a dedicated timestamped worklog structure.
- Established a top-level worklogs/ directory for detailed session records, separate from docs/engineering-log.md.
- Defined the timestamp convention YYYY-MM-DD_HHMM so worklog folders sort chronologically.
- Defined the intended session structure: detailed Word report, session-summary.md, and evidence/ subdirectory.
- Identified that Git does not track empty directories; a placeholder such as .gitkeep is required if an empty evidence/ folder must appear in the repository.
- Observed Git state showing the local main branch ahead of origin/main by one commit while the working tree was clean.
- Provided the PowerShell push workflow for synchronizing committed local changes to the GitHub remote.

worklogs/
└── 2026-08-13_2113/
├── PCB-001_Engineering_Log_2026-08-13.docx
├── session-summary.md
└── evidence/
└── .gitkeep

Traceability note: The conversation did not contain a final Git push success message, so remote synchronization should not be recorded as independently confirmed in this worklog.

# 4. Project Scheduling Refinement

The project schedule was revisited to keep PCB-001 moving without rushing into PCB layout. The key planning change was to separate analytical design, simulation verification, KiCad capture, footprint verification, PCB layout, and design review into distinct gates.

Stage | Purpose | Exit condition
Analytical design | Predict timing and LED behavior before simulation. | Equations and component values justified.
LTspice verification | Challenge analytical predictions with a device model. | Waveform and .meas agreement.
KiCad schematic | Capture the verified circuit. | ERC reviewed.
Footprint engineering | Map symbols to real packages. | All footprints checked.
PCB layout | Placement, routing, ground strategy. | Routed Rev-A candidate.
Design review | Independent-style review and DRC. | Design freeze decision.

## 14 August circuit-engineering block

- Replaced broad datasheet study with a 90-minute execution plan.
- Focused the block on timing-network design, LED current-limiting, complete circuit definition, and design-record updates.
- Added the rule that KiCad PCB layout should not begin until circuit behavior is understood and simulation-verified.

# 5. Analytical Baseline Before LTspice

Candidate midpoint design used for the first simulation:

Parameter | Value | Role
VCC | 5 V | NE555 supply
RA | 10 kOhm | Fixed charge-path resistor
RB | 60 kOhm | Midpoint effective timing resistance
C1 | 10 uF | Timing capacitor
C2 | 10 nF | Control-voltage bypass

## Threshold predictions

- Trigger threshold: VTRIG ≈ VCC/3 = 1.6667 V.
- Upper threshold: VTH ≈ 2VCC/3 = 3.3333 V.
- Expected steady-state capacitor behavior: VCAP repeatedly charges and discharges between these two levels.

## Timing equations

tHIGH = 0.693 (RA + RB) C
tLOW = 0.693 RB C
T = tHIGH + tLOW
f = 1 / T
Duty = 100 * tHIGH / T

Quantity | Analytical prediction
tHIGH | 0.485100 s
tLOW | 0.415800 s
Period T | 0.900900 s
Frequency f | 1.110001 Hz
Duty cycle | 53.8462 %

## LED output baseline

A 330 Ohm current-limiting resistor was selected for the first-pass LED branch. Using an idealized 5 V HIGH output and approximately 2 V LED forward drop gives about 9.1 mA, which is suitable as a first simulation target.

# 6. LTspice Circuit Construction

The circuit was constructed incrementally rather than all at once. This allowed each connection to be reviewed before the transient simulation was run.

1. Placed the built-in NE555 device model and a 5 V DC source.

2. Connected the NE555 GND pin to node 0 and tied RESET high to the VCC net.

3. Placed R1 = 10 kOhm from VCC to the DISCHARGE node.

4. Placed R2 = 60 kOhm from the DISCHARGE node to the timing node.

5. Joined TRIGGER and THRESHOLD to the timing node.

6. Placed C1 = 10 uF from the timing node to ground.

7. Placed C2 = 10 nF from CONTROL VOLTAGE to ground.

8. Added the LED output branch from OUT through D1 and R3 = 330 Ohm to ground.

9. Added C3 = 100 nF supply decoupling from VCC to ground.

10. Labeled the timing node VCAP and the output node VOUT for readable waveform and .meas references.

## Corrections made during construction

- The NE555 GND connection was initially omitted and then corrected.
- The control-voltage (CV) wiring was repeatedly checked because crossing wires made the schematic visually ambiguous.
- The LED resistor was initially shown as 10 kOhm and was corrected to 330 Ohm.
- The supply-decoupling capacitor C3 = 100 nF was added before the final simulation.
- The timing-node label VCAP was placed on the R2/TRIG/THRS/C1 junction.


Figure 1. First-pass LTspice schematic used for the successful transient verification.

# 7. Transient Simulation Setup

.tran 0 5s 0 1ms startup

- Stop time: 5 s, providing several steady-state oscillation cycles.
- Maximum timestep: 1 ms, providing adequate time resolution for the approximately 0.9 s period.
- startup enabled so the timing capacitor begins from an uncharged startup condition.
- First startup cycle treated as a transient and excluded from steady-state timing measurements.

## Observed waveforms


Figure 2. LTspice transient result: VOUT (green) and VCAP (blue).

- VOUT switches between approximately 0 V and 4.9 V.
- VCAP rises toward approximately 3.33 V while the output is HIGH.
- When VCAP reaches the upper threshold, VOUT switches LOW and the timing capacitor discharges.
- VCAP falls toward approximately 1.67 V; at the lower threshold VOUT switches HIGH again.
- The repeated charge/discharge behavior matches the intended astable operating cycle.

# 8. Numerical Verification Using .meas

The visual waveform check was upgraded to numerical verification using LTspice .meas statements. A 1 s delay was used so edge counting begins after the startup transient.

.meas tran tHIGH TRIG V(vout) VAL=2.5 TD=1s RISE=1 TARG V(vout) VAL=2.5 TD=1s FALL=1
.meas tran tLOW TRIG V(vout) VAL=2.5 TD=1s FALL=1 TARG V(vout) VAL=2.5 TD=1s RISE=2
.meas tran PERIOD TRIG V(vout) VAL=2.5 TD=1s RISE=1 TARG V(vout) VAL=2.5 TD=1s RISE=2
.meas tran FREQ PARAM 1/PERIOD
.meas tran DUTY PARAM 100*tHIGH/PERIOD
.meas tran VCAP_MIN MIN V(vcap) FROM 1s TO 5s
.meas tran VCAP_MAX MAX V(vcap) FROM 1s TO 5s

## LTspice 24.1.10 measurement results

Measurement | Result | LTspice interval/method
tHIGH | 0.485924888329 s | 1.18652501599 s -> 1.67244990432 s
tLOW | 0.416960804006 s | 1.67244990432 s -> 2.08941070833 s
Period | 0.902885692335 s | 1.18652501599 s -> 2.08941070833 s
Frequency | 1.10755991427 Hz | Derived as 1/PERIOD
Duty cycle | 53.819092766 % | Derived as 100*tHIGH/PERIOD
VCAP minimum | 1.66566741467 V | Measured from 1 s to 5 s
VCAP maximum | 3.33433270454 V | Measured from 1 s to 5 s

# 9. Analytical vs Simulation Comparison

Quantity | Analytical | LTspice | Relative error
tHIGH | 0.485100 | 0.485925 | +0.170%
tLOW | 0.415800 | 0.416961 | +0.279%
Period | 0.900900 | 0.902886 | +0.220%
Frequency | 1.110001 | 1.107560 | -0.220%
Duty cycle | 53.846154 | 53.819093 | -0.050%
VCAP min | 1.666667 | 1.665667 | -0.060%
VCAP max | 3.333333 | 3.334333 | +0.030%

Verification conclusion: The midpoint LTspice model agrees with the analytical model to substantially better than 1% for every measured timing and threshold quantity. The largest observed relative deviation is approximately 0.28% (tLOW). This is sufficient to mark the midpoint simulation verification as PASS.

# 10. Issues, Observations, and Lessons Learned

Observation | Engineering lesson / follow-up
Schematic readability matters | Wire crossings and long routing made CV, THRS, and timing-node connectivity harder to inspect than necessary. Future schematics should use net labels earlier and reduce long perimeter wires.
Git tracks files, not folders | Empty evidence directories will not appear in GitHub unless they contain a tracked placeholder or real artifact.
Simulation should verify a prediction | The analytical model was completed before LTspice; the simulator was therefore used as a verification tool rather than a discovery tool.
Startup is not steady state | The first timing-capacitor cycle begins from 0 V and should not be used for steady-state period measurements.
Ideal equations are still useful | Despite the more realistic NE555 model, the basic ln(2)-based timing equations predicted the observed behavior extremely closely.
Project paths need normalization | The LTspice log shows a generated netlist under simulation\simulation\ltspice. The intended repository structure is simulation\ltspice; this duplicate directory level should be checked and cleaned up before the next commit.

# 11. Artifacts Created or Updated During This Work Period

Artifact | Reference | Status
LTspice schematic | pcb001_ne555_astable.asc | Constructed and simulation-tested.
LTspice generated netlist | pcb001_ne555_astable.net | Generated by LTspice 24.1.10.
Simulation evidence | V(vout) and V(vcap) transient waveform | Successful steady-state astable behavior.
Measurement configuration | .meas directives | Numerical HIGH/LOW/period/frequency/duty/threshold verification.
Worklog structure | worklogs/YYYY-MM-DD_HHMM/ | Timestamped session-document convention established.
Project schedule | 14-24 August sequence | Revised to insert LTspice verification before KiCad.

# 12. Project Status at 08:29, 14 August 2026

Work item | Status | Comment
Project/repository structure | ACTIVE | Worklog convention refined; remote sync should be rechecked.
NE555 functional understanding | COMPLETE | Astable threshold and charge/discharge behavior understood.
Analytical midpoint design | COMPLETE | Timing and duty predictions established.
LTspice midpoint construction | COMPLETE | Circuit runs correctly.
LTspice midpoint .meas verification | PASS | Sub-0.3% timing error vs ideal model.
Potentiometer range sweep | NOT STARTED | RB = 10 kOhm, 60 kOhm, 110 kOhm still to verify as a set.
KiCad schematic capture | NOT STARTED | Blocked until full simulation gate is closed.

# 13. Next Work Session - Recommended Actions

1. Parameterize RB in LTspice and run the same numerical checks at 10 kOhm, 60 kOhm, and 110 kOhm.

2. Confirm the expected full flash-rate range (approximately 4.81 Hz at minimum resistance and 0.627 Hz at maximum resistance).

3. Measure LED current with .meas or direct waveform probing and verify the 330 Ohm resistor choice.

4. Normalize the LTspice repository path so files live under simulation\ltspice rather than simulation\simulation\ltspice.

5. Save simulation screenshots and measurement output into the timestamped evidence folder.

6. Update docs/design-notes.md with the final verified component values and analytical-vs-simulation table.

7. Commit the completed simulation evidence to Git and confirm origin/main is synchronized.

8. Only after the full-range simulation gate passes, begin KiCad schematic capture.

# 14. Suggested Gate Decision

G1B - Simulation Verification: CONDITIONAL PASS

Reason: The midpoint configuration is fully verified and passes comfortably. However, the intended adjustable design spans RB = 10 kOhm to 110 kOhm. The project should not formally freeze the timing network until the minimum and maximum settings have also been simulated and measured.

# 15. Session Closeout

- Technical objective achieved: a working NE555 astable LTspice model has been constructed and numerically validated at the midpoint configuration.
- Project-management objective achieved: the workflow now has a clear prediction -> simulation -> comparison -> gate structure.
- No KiCad layout work was started prematurely.
- Primary remaining dependency before schematic freeze: full timing-resistance sweep and associated measurement evidence.

Document generated at the 08:29 worklog cutoff on 14 August 2026. Measurements transcribed from the LTspice 24.1.10 SPICE Error Log supplied during the session.

PCB-001 | NE555 Astable LED Flasher | Engineering Worklog

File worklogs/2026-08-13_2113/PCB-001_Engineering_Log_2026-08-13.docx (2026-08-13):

PCB-001

# Engineering Log - Day 1

Adjustable NE555 Astable LED Flasher PCB

Project planning, circuit understanding, datasheet review, MATLAB modelling, and repository preparation

Session date: Thursday, 13 August 2026

End-of-day log prepared at approximately 19:33 (Europe/Dublin)

DAY 1 OUTCOME

The project moved from an idea into a defined engineering project with a clear scope, requirements baseline, staged lifecycle, selective NE555 knowledge base, a MATLAB animation artifact, and a planned Git/GitHub repository structure. Physical PCB design and circuit-value finalisation have not yet been completed.

# 1. Project status overview

Project objective. Design, manufacture, assemble, and validate a two-layer adjustable LED flasher PCB using an NE555 timer in astable mode, while using the project to practise disciplined engineering planning, documentation, verification, and version-control habits.

Field | Current status
Project identifier | PCB-001
Working title | Adjustable NE555 Astable LED Flasher
Current phase | Planning / Circuit Engineering
Current project gate | G0 planning baseline substantially established; Phase 1 circuit engineering underway
Primary CAD tool | KiCad
Supporting analysis tool | MATLAB
Nominal supply | 5 V DC
Target PCB | 2-layer board, primarily through-hole components

# 2. Tasks completed today

Important status note: This log distinguishes between work that was actually completed in today's project session and work that was only planned. The local directory, Git repository, and GitHub repository were designed in detail but their creation has not been independently confirmed in this session.

Task | Status | What was achieved | Evidence / output
Project selection and scope definition | Completed | The first KiCad learning project was fixed as an adjustable NE555 astable LED flasher. Scope was deliberately constrained to a simple oscillator, one LED, an adjustable flash rate, 5 V operation, two PCB layers, and testability. Scope-control was explicitly treated as a project-management skill. | PCB-001 scope and project charter
Project charter and learning objectives | Completed | Defined the project objective and the learning outcomes: schematic capture, footprint selection, PCB layout, DRC/ERC, fabrication outputs, assembly, bring-up, measurement, documentation, and retrospective. | Project objectives and lifecycle notes
Requirements baseline | Completed | Established functional, PCB, and verification requirements, including continuous LED flashing, adjustable frequency, 5 V operation, NE555 astable topology, test points, 2-layer PCB construction, ERC/DRC expectations, and hardware measurement requirements. | FR/PCB/VER requirement set
Lifecycle, gates, milestones, and Definition of Done | Completed | Outlined the project from planning through circuit engineering, schematic capture, footprint verification, PCB layout, design review, fabrication, assembly, bring-up, validation, and closure. Milestones M0-M9 and review gates were introduced. | M0-M9 milestone plan and gate logic
Initial risk register | Completed | Identified risks including wrong footprint selection, polarity errors, incorrect 555 wiring, PCB shorts, connector mismatch, soldering defects, frequency mismatch, and scope creep. | R1-R9 risk list and mitigations
Two-week work plan | Completed | Mapped the project into staged work blocks for 13-23 August 2026, with circuit engineering first, then schematic capture, footprint review, PCB layout, and design review. | 13-23 Aug staged schedule
Circuit Engineering time-block definition | Completed | Prepared a detailed session description for 14 August focused on understanding only the NE555 behaviour needed to design the circuit. | 14 Aug session description
Selective NE555 datasheet review | Completed | Reviewed the uploaded NE555 datasheet selectively rather than reading it line-by-line. Extracted the pinout, internal functional blocks, valid supply range, trigger/threshold levels, and manufacturer astable application topology. | NE555.PDF reviewed, especially pp. 1, 2, 4, 6
NE555 astable operating-cycle understanding | Completed | Established the practical mental model: the timing capacitor moves between approximately 1/3 VCC and 2/3 VCC; the comparators and internal latch switch the output state; pin 7 provides the discharge path; the output waveform controls the LED ON/OFF behaviour. | Charge/discharge mental model
Key datasheet notes distilled | Completed | Converted the datasheet into a concise bullet-point reference containing the information needed for PCB-001 and a list of sections that can be ignored at this stage. | Bullet-point datasheet reference
MATLAB animation artifact | Completed | Created a MATLAB script named ne555_astable_cycle_animation.m that animates capacitor charging/discharging and the corresponding pin-3 output waveform. Initial parameters were VCC = 5 V, RA = 10 kOhm, RB = 50 kOhm, and C = 10 uF. | ne555_astable_cycle_animation.m
Repository/folder architecture | Prepared | Designed a professional but lightweight repository structure for KiCad sources, MATLAB simulation, requirements/design/test documentation, datasheets, BOM, fabrication files, and evidence images. Git/GitHub creation commands and a staged commit strategy were also specified. | Recommended folder tree and Git command sequence

# 3. Technical understanding established today

## 3.1 NE555 role in PCB-001

- The NE555 is being used in astable mode as a free-running oscillator.
- The external timing network (RA, RB, and C) controls how quickly the timing capacitor charges and discharges and therefore controls the output switching rate.
- Pin 3 produces the HIGH/LOW output waveform that will drive the LED through a current-limiting resistor.
- The timing capacitor itself does not directly drive the LED; it controls when the internal 555 state changes.

## 3.2 Pin-level knowledge retained

- 1 - GND: 0 V reference.
- 2 - TRIGGER: Monitors the lower timing threshold.
- 3 - OUTPUT: Produces the switching waveform that regulates LED ON/OFF state.
- 4 - RESET: Can force the timer into reset; planned to be held inactive for normal operation.
- 5 - CONTROL VOLTAGE: Provides access to the internal reference; not part of the user flash-rate adjustment.
- 6 - THRESHOLD: Monitors the upper timing threshold.
- 7 - DISCHARGE: Provides the controlled discharge path for the timing capacitor.
- 8 - VCC: Positive supply; PCB-001 nominally uses 5 V.

## 3.3 Astable operating cycle

1. The timing capacitor voltage is near the lower trigger level, approximately 1/3 VCC.
2. The internal state causes pin 3 OUTPUT to go HIGH and the discharge path at pin 7 to turn OFF.
3. The capacitor charges through the timing-resistor path toward the upper threshold.
4. When the capacitor reaches approximately 2/3 VCC, the threshold comparator changes the internal state.
5. Pin 3 OUTPUT goes LOW and the pin-7 discharge path turns ON.
6. The capacitor discharges through the appropriate timing resistance.
7. When the capacitor voltage falls back to approximately 1/3 VCC, the cycle restarts.
8. The repeating HIGH/LOW output is therefore the electrical control signal for the LED flashing pattern.

## 3.4 Why this understanding matters

- It allows component values to be chosen intentionally rather than copied from a tutorial.
- It explains why increasing timing resistance or capacitance slows the LED flash rate.
- It provides a basis for calculating expected frequency and comparing it with oscilloscope measurements later.
- It creates a clear debugging path if the finished PCB does not oscillate or the LED behaves unexpectedly.

# 4. Datasheet review scope and decisions

Source used: Philips Semiconductors, Timer NE/SA/SE555/SE555C Product Specification (31 August 1994), uploaded as NE555.PDF.

Sections judged relevant now:

- Page 1: device purpose, astable capability, output capability, and 8-pin package/pin configuration.
- Page 2: functional block diagram (comparators, flip-flop, output stage, discharge function).
- Page 4: supply-voltage range and typical trigger/threshold levels at 5 V.
- Page 6: manufacturer astable application topology and timing relationship.

Sections intentionally deferred:

- Transistor-level equivalent schematic.
- Detailed high-frequency and propagation-delay curves.
- Temperature-drift and extreme-environment analysis.
- Monostable operation and AC-coupled triggering details.
- Detailed trigger pulse-width behaviour not required for a simple free-running oscillator.

# 5. MATLAB animation artifact created

Artifact: ne555_astable_cycle_animation.m

- Animates the timing capacitor voltage over several astable cycles.
- Shows the capacitor moving between the 1/3 VCC and 2/3 VCC reference levels.
- Shows the corresponding pin-3 output waveform.
- Updates the state label between CHARGING and DISCHARGING.
- Explains whether the pin-7 discharge path is ON or OFF in each state.
- Allows VCC, RA, RB, C, and number of cycles to be changed for experimentation.
- Includes an optional MP4 export switch.

Parameter | Initial value | Purpose in model
VCC | 5 V | Supply and threshold scaling
RA | 10 kOhm | Part of charge path
RB | 50 kOhm | Charge/discharge timing resistance
C | 10 uF | Timing capacitor
Cycles | 3 | Animation duration

# 6. Project-management practices exercised today

- Scope control: deliberately kept PCB-001 small and excluded microcontrollers, Bluetooth, displays, FPGA interfaces, and other scope-expanding features.
- Requirements-before-CAD thinking: defined success criteria before KiCad schematic/layout work.
- Stage-gate planning: separated planning, circuit engineering, schematic, footprint review, layout, design review, fabrication, bring-up, validation, and closure.
- Risk management: identified likely failure modes before fabrication.
- Evidence-driven completion: defined deliverables and exit conditions instead of treating time spent as proof of progress.
- Time-boxing: compressed datasheet review to the subset needed for the current design stage.
- Traceability: planned engineering log, requirements, test-plan, and test-report documents.
- Version-control discipline: designed a commit sequence that records genuine project progression rather than one final bulk upload.

# 7. Decision register

ID | Decision | Rationale | Status
D-001 | Use an NE555 astable LED flasher as PCB-001. | Simple enough to complete end-to-end while still teaching the complete PCB lifecycle. | Accepted
D-002 | Use nominal 5 V operation. | Within the NE555 operating range and convenient for a beginner PCB. | Accepted
D-003 | Prioritise through-hole components where practical. | Simplifies first-board assembly and visual inspection. | Accepted
D-004 | Do not read the entire NE555 datasheet in detail at this stage. | Only pinout, operating thresholds, block-level behaviour, supply limits, and astable topology are currently needed. | Accepted
D-005 | Use MATLAB as a supporting learning/verification artifact. | Animation makes the relationship between capacitor voltage and output switching explicit. | Accepted
D-006 | Use a structured GitHub repository with source, docs, fabrication, BOM, simulation, and evidence folders. | Supports traceability and portfolio-quality documentation. | Prepared; creation not confirmed

# 8. Repository structure prepared today

pcb-001-ne555-astable-led-flasher/
|-- README.md
|-- LICENSE
|-- .gitignore
|-- hardware/
| `-- kicad/
|-- simulation/
| `-- matlab/
| `-- ne555_astable_cycle_animation.m
|-- docs/
| |-- requirements.md
| |-- design-notes.md
| |-- engineering-log.md
| |-- test-plan.md
| |-- test-report.md
| `-- datasheets/
| `-- NE555.pdf
|-- bom/
|-- fabrication/
| |-- gerbers/
| `-- drill/
`-- images/
|-- schematic/
|-- pcb-layout/
|-- renders/
|-- assembly/
`-- test-evidence/

Status: This structure and the Git/GitHub command sequence were prepared today. The log does not claim that the local directories or remote GitHub repository were successfully created, because that completion was not confirmed in the session.

# 9. Work not yet completed

- Final RA, RB/potentiometer, timing-capacitor, and LED-resistor values have not yet been frozen.
- Minimum, midpoint, and maximum flash-rate calculations have not yet been completed as final design calculations.
- A final hand-drawn circuit has not yet been reviewed and signed off.
- The KiCad project, schematic, symbol assignments, and footprints have not yet been created/verified.
- PCB placement, routing, ground pour, ERC/DRC, Gerbers, BOM release, fabrication, assembly, and physical validation remain future work.
- Creation of the local project directory, Git repository, and GitHub remote has been planned but not confirmed as executed.

# 10. Recommended next-session objectives - 14 August 2026

- Complete only the circuit calculations required to choose the timing network.
- Select provisional RA, RB/potentiometer, C, and LED current-limiting resistor values.
- Calculate expected tHIGH, tLOW, period, frequency, and duty cycle at useful potentiometer positions.
- Draw the complete proposed circuit and verify every NE555 pin connection against the datasheet/application diagram.
- Record the chosen values and reasoning in design-notes.md.
- If the project directory/repository has not yet been created, create it and make the first small Git commit before further CAD work.

# 11. Day 1 reflection

The strongest outcome from today was not a PCB layout; it was the reduction of ambiguity. The project now has a controlled scope, clear success criteria, a staged execution plan, a focused technical knowledge base, and a reproducible supporting MATLAB artifact. The main efficiency improvement introduced today was recognising that engineering does not require exhaustive reading of every datasheet detail before progress can be made. The appropriate level of detail depends on the design stage and the risks currently being addressed.

End-of-day gate assessment: Planning is sufficiently mature to continue into circuit engineering, but the project is not ready for PCB layout. The immediate technical gate is to finalise and justify the timing-network and LED component values, then capture a correct KiCad schematic.

# 12. Reference material used

Philips Semiconductors. Timer NE/SA/SE555/SE555C Product Specification. 31 August 1994. Uploaded project reference: NE555.PDF. Pages consulted today included the device description/pinout, block diagram, electrical characteristics, and typical astable application.

NE555 Astable LED Flasher - Day 1 Project Record

PCB-001 | Engineering Log | 13 August 2026

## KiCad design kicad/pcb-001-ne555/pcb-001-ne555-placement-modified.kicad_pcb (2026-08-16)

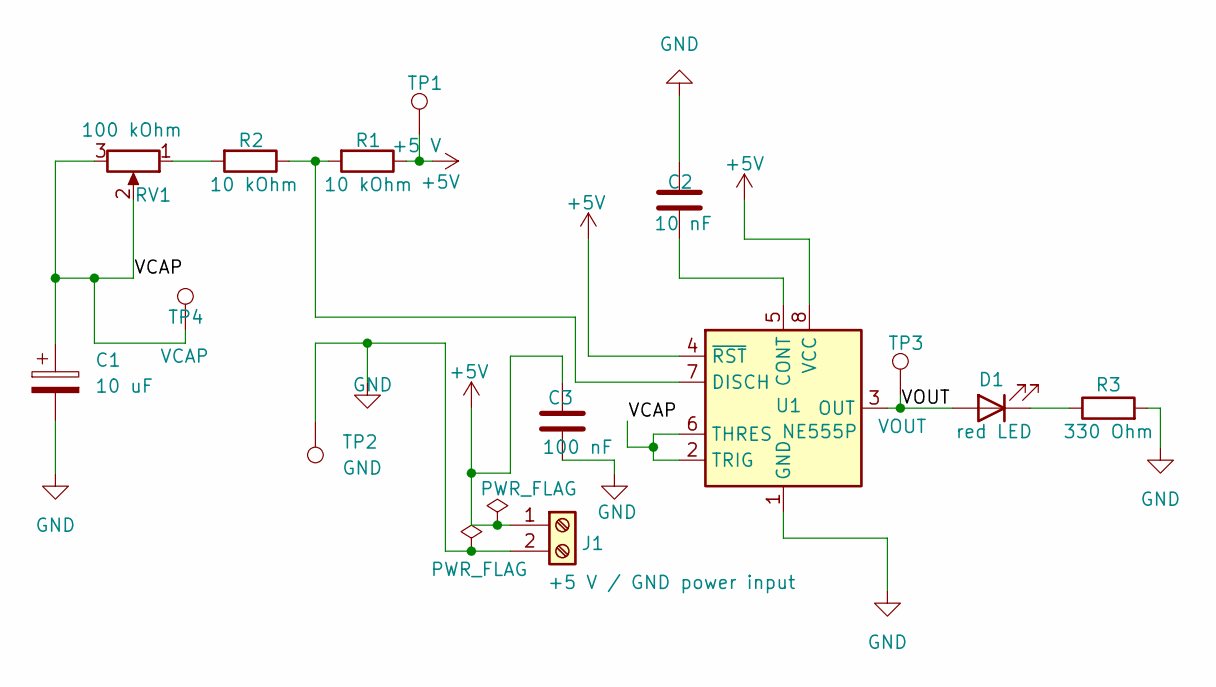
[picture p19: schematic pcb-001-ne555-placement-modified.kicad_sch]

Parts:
C1: 10 uF; CP_Radial_D5.0mm_P2.00mm
C2: 10 nF; C_Disc_D5.0mm_W2.5mm_P5.00mm
C3: 100 nF; C_Disc_D5.0mm_W2.5mm_P5.00mm
D1: red LED; LED_D5.0mm
J1: +5 V / GND power input; TerminalBlock_CUI_TB007-508-02_1x02_P5.08mm_Horizontal
R1, R2: 10 kOhm; R_Axial_DIN0207_L6.3mm_D2.5mm_P10.16mm_Horizontal
R3: 330 Ohm; R_Axial_DIN0207_L6.3mm_D2.5mm_P10.16mm_Horizontal
RV1: 100 kOhm; Potentiometer_Bourns_3386P_Vertical
TP1: +5 V; TestPoint_THTPad_D2.0mm_Drill1.0mm
TP2: GND; TestPoint_THTPad_D2.0mm_Drill1.0mm
TP3: VOUT; TestPoint_THTPad_D2.0mm_Drill1.0mm
TP4: VCAP; TestPoint_THTPad_D2.0mm_Drill1.0mm
U1: NE555P; DIP-8_W7.62mm

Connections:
+5V: C3.1, J1.1, R1.1, TP1.1 (1_1), U1.4 (~RST), U1.8 (VCC)
/VCAP: C1.1, RV1.2, RV1.3, TP4.1 (1_1), U1.2 (TRIG), U1.6 (THRES)
/VOUT: D1.2 (A), TP3.1 (1_1), U1.3 (OUT)
GND: C1.2, C2.1, C3.2, J1.2, R3.2, TP2.1 (1_1), U1.1 (GND)
unnamed: D1.1 (K), R3.1
unnamed: R2.2, RV1.1
unnamed: C2.2, U1.5 (CONT)
unnamed: R1.2, R2.1, U1.7 (DISCH)

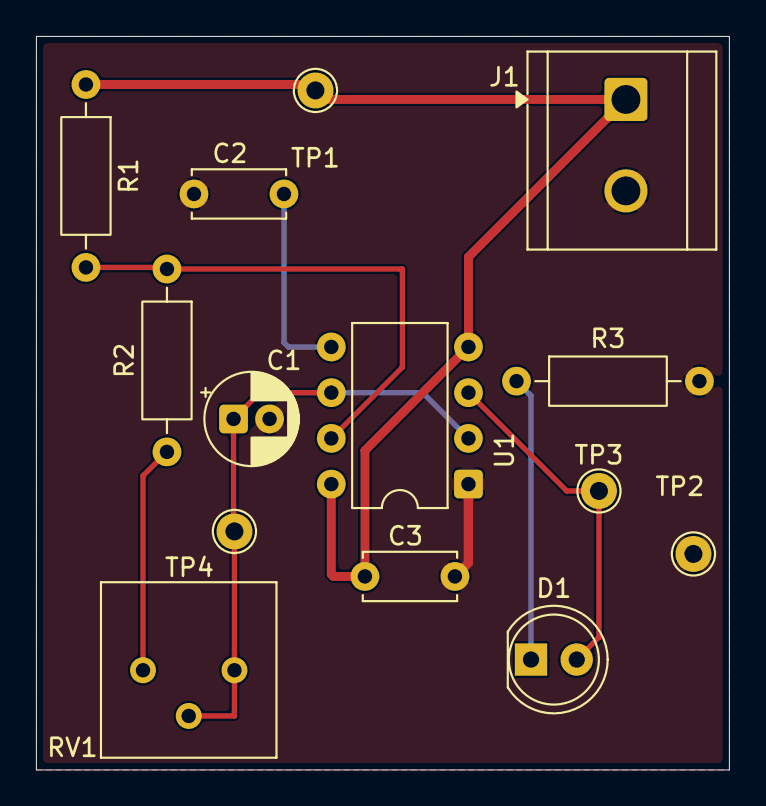
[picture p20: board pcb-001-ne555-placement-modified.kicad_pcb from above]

Board: 2 copper layers, 38.5 x 40.8 mm, 14 parts (0 on the bottom side), 8 nets.

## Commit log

2026-08-13 chore: initialize PCB-001 project structure
2026-08-13 docs: add PCB-001 project initiation worklog
2026-08-14 docs(verification): preserve 14 August circuit verification evidence
2026-08-15 fix(tinkercad): reject partial cycles in Arduino logger
    [pcb001_ne555_logger.ino]
2026-08-15 chore(kicad): initialize PCB-001 project scaffold
    [pcb-001-ne555.kicad_pcb, pcb-001-ne555.kicad_sch]
2026-08-15 chore(repo): ignore KiCad transient files
2026-08-15 Update project files 2026-08-15 23:55:03
    [pcb-001-ne555.kicad_pcb, pcb-001-ne555.kicad_sch]
2026-08-16 Update project files 2026-08-16 01:39:38
    [pcb-001-ne555-placement-modified.kicad_pcb, pcb-001-ne555-placement-modified.kicad_sch, pcb-001-ne555.kicad_sch]
2026-08-16 Update project files 2026-08-16 14:48:06
    [pcb-001-ne555-placement-modified.kicad_pcb, pcb-001-ne555-placement-modified.kicad_sch]
